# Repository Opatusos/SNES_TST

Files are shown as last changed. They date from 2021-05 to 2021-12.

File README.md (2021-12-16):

# SNES-TST

This projects intends to clean up the blurry RGB video on the 3-chip SNES by using the PPU2's test pins. The board has only been tried on a SNSP-CPU-01 motherboard but it should work with all revisions. The firmware is missing most of the board's functions. The planned functions are the following:
- dual analog ouput (verified, need further noise analysis, furthermore direct comparision is needed to the original video)
- Mode-7 patch for the test pins (verified)
- SuperCIC (verified)
- dual-frequency oscillator (not tested)
- controller support (partwise verified)
- dejitter (not tested)
- D4 patch (not tested)
- RGB LED support with PWM (not tested)

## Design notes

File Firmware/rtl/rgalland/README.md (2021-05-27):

# snes_cic_fpga
snes cic implementation with FPGA FireAnt board

https://www.crowdsupply.com/xips-technology/fireant

Personally I got this board from Mouser, but the board comes without the packaging that contains the serial number that is normally required to register the device with Efinix (https://www.efinixinc.com/products-efinity.html). I contacted them to create an account in order to download the IDE and have access to support.

FireAntInAction

FireAnt on the right connected to SMW PCB. Little LED next to USB conenctor is on showing that reset has been released. On the left of the image, there is PIC16F that I used to compare the outputs.

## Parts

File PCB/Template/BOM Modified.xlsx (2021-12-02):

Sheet: BOM Report
Bill of Materials
Source Data From: |  | Field=DataSourceFileName
Project: |  | Field=ProjectFileName
Variant: |  | Field=VariantName
Revision: |  | Field=Revision
Currency: |  | Field=Currency
Creation Date: | Field=ReportDate | Field=ReportTime
Print Date: | 2021-12-01 | 16:24:10
Column=Line # | Column=Quantity | Column=Designator | Column=Comment | Column=Footprint | Column=Manufacturer | Column=Manufacturer_Part_Number | Column=Supplier 1 | Column=Supplier Part Number 1 | Column=Supplier Unit Price 1 | Total Price
 |  |  |  |  |  |  |  |  |  | 0.00
 |  |  |  |  |  |  |  |  |  | 0.00
 |  |  |  |  |  |  |  |  |  | 0.00
 | 0 |  |  |  |  |  |  |  |  | $0.00

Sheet: Project Information
Project Filename | Field=ProjectFileName
Variant Name | Field=VariantName
Data-Source Filename | Field=DataSourceFileName
Title | Field=Title
Total Quantity | Field=TotalQuantity
Report Time | Field=ReportTime
Report Date | Field=ReportDate
Report Date & Tine | Field=ReportDateTime
Output Name | Field=OutputName
Output Type | Field=OutputType
Output Generator Name | Field=GeneratorName
Output Generator Description | Field=GeneratorDescription

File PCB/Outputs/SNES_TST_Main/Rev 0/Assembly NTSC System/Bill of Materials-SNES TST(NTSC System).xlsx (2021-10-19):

Pos # | Quantity | Designator | Value | Tolerance | Nominal Voltage | Dielectric | Footprint | Vendor | Part Number
1 | 27 | C1, C2, C3, C4, C5, C6, C11, C12, C13, C14, C15, C16, C17, C18, C19, C20, C21, C22, C23, C24, C25, C26, C27, C28, C29, C30, C32 | 100nF | +-20% | 10V | X7R | Cap_0402_Chip
2 | 4 | C7, C8, C9, C10 | 10pF | +-20% | 10V | X7R | Cap_0402_Chip
3 | 3 | C31, C33, C34 | 10nF | +-20% | 10V | X7R | Cap_0402_Chip
4 | 1 | C35 | 1uF | +-20% | 10V | X7R | Cap_0603_Chip
5 | 1 | C36 | 10uF | +-20% | 10V | X7R | Cap_0805_Chip
6 | 1 | C37 | 10uF | +-20% | 25V | X7R | Cap_1206_Chip
7 | 4 | D1, D2, D3, D4 | Schottky Diode |  |  |  | SOD323 | Diodes | BAT54WS-7-F
8 | 4 | FB1, FB2, FB3, FB4 | 1800Ohm 200mA |  |  |  | Ind_0402_Chip | TDK | MMZ1005S182ET000
9 | 1 | IC1 | 10M04SAE144C8G |  |  |  | EQFP-144_A:1P65_ | Intel | 10M08SAE144C8G
10 | 1 | IC2 | 17.734475 MHz |  |  |  | Quarz 7.5mm | IQD Frequency | LFSPXO020648Bulk
11 | 1 | IC3 | TMUX1219 |  |  |  | SOT23-6 | Texas Instruments | TMUX1219DBVR
12 | 1 | IC5 | SN74HCT541 |  |  |  | TSSOP20 Narrow | Texas Instruments | SN74HCT541PW
13 | 7 | IC6, IC7, IC8, IC9, IC10, IC11, IC12 | LSF0108 |  |  |  | VQFN20 | Texas Instruments | LSF0108RKS
14 | 2 | IC13, IC15 | OPA2356 |  |  |  | MSOP8 | Analog Devices | OPA2356AIDGK
15 | 1 | IC14 | TMUX1574 |  |  |  | SOT-23THIN16 | Texas Instruments | TMUX1574DYYR
16 | 1 | IC16 | ADV7123 |  |  |  | ST_48_ADI | Analog Devices Inc | ADV7123KSTZ50
17 | 1 | IC17 | THS7374 |  |  |  | TSSOP14 | Texas Instruments | THS7374IPW
18 | 1 | IC18 | MCP1703T |  |  |  | SOT223-3 | Microchip | MCP1703T-3302E/DB
19 | 1 | J2 | 80Pole Connector |  |  |  | DF40C-80DP | Hirose Connector | DF40C-80DP-0.4V(51)
20 | 1 | Q1 | IRLML6402 |  |  |  | SOT23_FET | Diodes | IRLML6402
21 | 1 | Q2 | MMBT3904 |  |  |  | SOT23_Transistor | Diodes | MMBT3904
22 | 1 | Q3 | BSS138 |  |  |  | SOT23_FET | Infenion | BSS138
23 | 6 | R1, R4, R28, R50, R55, R63 | 1k | +-1% |  |  | Res_0402_Chip
24 | 12 | R2, R3, R5, R17, R18, R19, R41, R42, R43, R58, R66, R78 | 10k | +-1% |  |  | Res_0402_Chip
25 | 5 | R6, R7, R12, R14, R44 | 470R | +-1% |  |  | Res_0603_Chip
26 | 4 | R8, R11, R13, R21 | 300R | +-1% |  |  | Res_0603_Chip
27 | 4 | R9, R49, R54, R60 | 0R |  |  |  | Res_0402_Chip
28 | 2 | R15, R20 | 33R | +-1% |  |  | Res_0603_Chip
29 | 1 | R16 | 100R | +-1% |  |  | Res_0603_Chip
30 | 8 | R22, R24, R25, R33, R34, R38, R39, R40 | 1.8k | +-1% |  |  | Res_0402_Chip
31 | 3 | R23, R26, R27 | 10k | +-1% |  |  | 1206_Array_Chip
32 | 7 | R29, R30, R31, R32, R35, R36, R37 | 200k | +-1% |  |  | Res_0402_Chip
33 | 1 | R45 | 1.24k | +-1% |  |  | Res_0402_Chip
34 | 4 | R46, R52, R57, R65 | 619R | +-1% |  |  | Res_0402_Chip
35 | 1 | R47 | 91R | +-1% |  |  | Res_0603_Chip
36 | 4 | R48, R53, R59, R81 | 100k | +-1% |  |  | Res_0402_Chip
37 | 3 | R51, R56, R64 | 237R | +-1% |  |  | Res_0402_Chip
38 | 1 | R61 | 470R | +-1% |  |  | Res_0402_Chip
39 | 1 | R62 | 11R | +-1% |  |  | Res_0402_Chip
40 | 6 | R67, R68, R69, R70, R77, R79 | 75R | +-1% |  |  | Res_0603_Chip
41 | 6 | R71, R72, R73, R74, R75, R76 | 75R | +-1% |  |  | Res_0402_Chip
42 | 3 | R80, R82, R83 | 3.3k | +-1% |  |  | Res_0402_Chip

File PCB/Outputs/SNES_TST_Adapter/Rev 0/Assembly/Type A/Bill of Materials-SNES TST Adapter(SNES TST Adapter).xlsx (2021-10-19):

Pos # | Quantity | Designator | Value | Tolerance | Nominal Voltage | Dielectric | Footprint | Vendor | Part Number
1 | 1 | J1 | 80Pole Connector |  |  |  | DF40C-80DS | Hirose Connector | DF40C-80DS-0.4V(51)

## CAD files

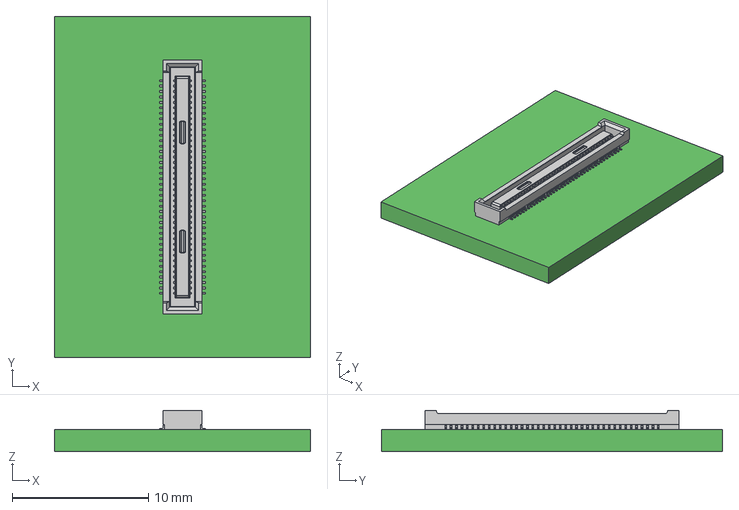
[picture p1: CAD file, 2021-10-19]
PCB/Outputs/SNES_TST_Adapter/Rev 0/Documentation/Type A/SNES TST Adapter Type A(SNES TST Adapter).step
18.8 x 25.0 x 3.04 mm
DF40C-80DS

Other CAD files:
PCB/Outputs/SNES_TST_Adapter/Rev 0/Documentation/Type B/SNES TST Adapter Type B(SNES TST Adapter).step

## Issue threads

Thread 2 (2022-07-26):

WE-MAPI_3020 Inductor

unmaker64, 2022-07-26:
Hi is this the correct inductor?

https://www.mouser.com/ProductDetail/Wurth-Elektronik/74438336068?qs=iC14BvcgY%2F2jjdn7Q0ci3w%3D%3D

Also wondering if this project will still be worked on, if you don't mind sharing.

Thanks

Opatusos, 2022-07-26:
Hi!

Is it from the dev branch? This inductor should be the correct one.
It is being worked on in theory, but I have not touched it since January. Hopefully I will find some time for it soon.

unmaker64, 2022-07-26:
Thank you for the quick reply!

I'm not sure how to find the most recent BOM within the dev branch tbh.

I had a look at the PCB in Altium and could see the part is described as "WE-MAPI_3020". These WE-MAPI_3020 inductors range in value from 330 nH to 10 uH. I tried to determine the correct value by looking at the datasheet for the ADP2370 and found this:

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

Using that formula I get an inductance value of 6.8 uH, assuming the Vout is 3.3v and the switching frequency is 1.2 MHz. I'm sort of guessing here so I wanted to check with you.

unmaker64, 2022-07-26:
I'm glad to hear that you haven't abandoned it! I look forward to seeing your progress on this when you have the time.

I'm not in a hurry to assemble a board anyway as I can't find the 10m04sae144c8g in stock anywhere. Which brings up another question I have: are other Altera MAX 10 FPGA's compatible? For example, a 10m08sae144c8g or 10M50SAE144I7G? A few of those have sold recently on ebay, which is the only place I've been able to find an FPGA.

Opatusos, 2022-07-27:
You were correct, it is 6.8 uH, but for some reason it shows 0603 in the comment field instead of the value. I really like this ADP2370 combined with the LT3045 LDO. I have also made an LM7805 replacement board with these two. It delivers up to 800 mA and has reasonably low noise.

The FPGA should be compatible up to 10M25SA, but not with the 10M50SA. Not sure what is the difference.
I have attached a quick export of the BOM. But as I see most of the semiconductors are not in stock unfortunately.
[SNES TST Main.xlsx](https://github.com/Opatusos/SNES_TST/files/9203990/SNES.TST.Main.xlsx)

unmaker64, 2022-07-28:
I really appreciate the BOM export. I was making my own by looking at the PCB in Altium.

In the BOM I can see the ferrite beads you've chosen are 0402 in size yet the PCB footprint is 0603. I know, not a big deal as 0402 components can fit in a 0603 footprint. I'm just wondering if that was a small mistake. I had picked these just to match the 0603 footprint:

https://www.mouser.com/ProductDetail/810-MMZ1608R102ATD25

Yeah the parts shortage really sucks. I figured I'd order what's currently available before they go out of stock again. I've been able to find more than I expected actually. What I have left to find now are the:

1. FPGA
2. DAC
3. clock
4. TMUX1574DYYR
5. IRLML6402

A few of those are available on ebay/aliexpress. I might take a gamble on them if it comes to that. If/when I'm able to find the remaining parts then I'll order some PCBs and report back here. Thanks again for your time.

Opatusos, 2022-08-04:
Yeah, I've changed the ferrite but did not change the details yet, as it was/is still WIP.

I have never tested this new version in the dev branch, so I'm not sure if it works at all. I still wanted to change the RGB lines from single-ended to differential. Right now I get GND interference if I connect the RGB signals to the Multiout connector.

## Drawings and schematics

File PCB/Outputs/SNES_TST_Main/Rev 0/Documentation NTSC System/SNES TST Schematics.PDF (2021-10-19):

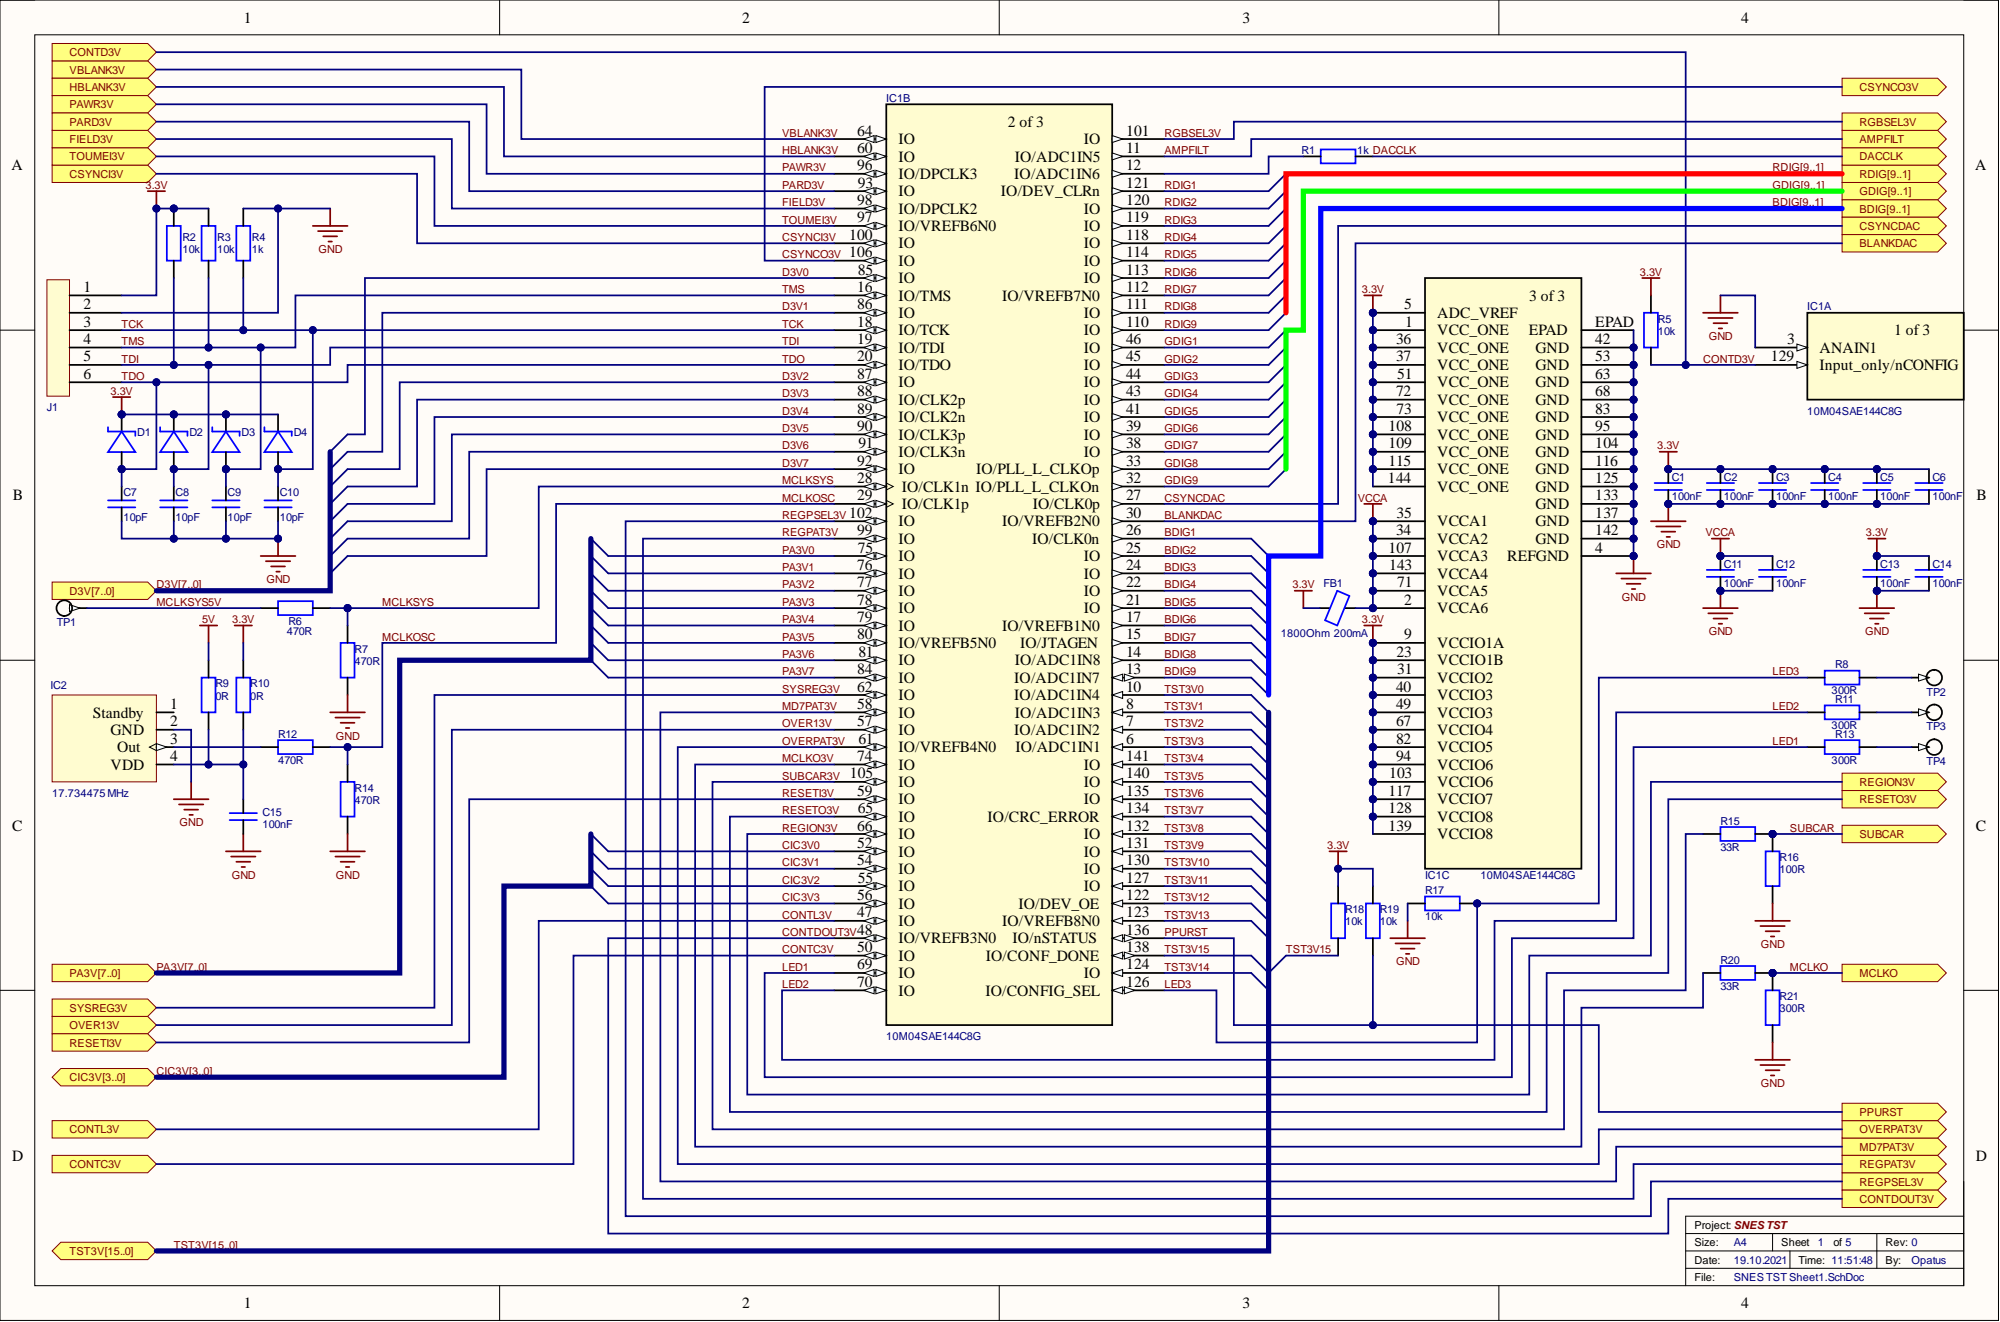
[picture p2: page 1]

H B L A N K 3 | V 6 0 | 1 1
P AW R 3 V | 9 6 | 1 2 | | | R D I G [ 9 . . 1 ]

T O UME I 3 | 9 7 V | 1 1 9 R D I G 3

123456 T C K | | | | T C K | 1 8 | 1 1 0 | R D I G 9 | 1 | A DC_ V RE F VCC_ O N E E PA D VCC_ O N E G N D VCC_ O N E G N D | E PA D | C O | N D | 3 | A N In p | 1 of 3 A IN 1 u t _ o n l y / n C O N FI G

R E G PAT 3 | 9 9 V | 3 V | 3 4 | VCCA 2 G N D VCCA 3 REFG N D VCCA 4 VCCA 5 VCCA 6 VCCIO 1 A VCCIO 1 B VCCIO 2 VCCIO 3 | 1 4 2 | C A G R

C I C 3 V 0 | 5 2
C I C 3 V 1 | 5 4

C I C 3 V 3 | 5 6
C O N T L 3 V | 4 7
C O N T D O | 4 8 U T 3 V
C O N T C 3 V | 5 0 | | 1 3 8 1 2 4 1 2 6 | T S T 3 V 1 5 T S T 3 V 1 4 L E D 3 | T S T 3 V 1 5

i z : A | f | R v
a . | ime | B y O p u s

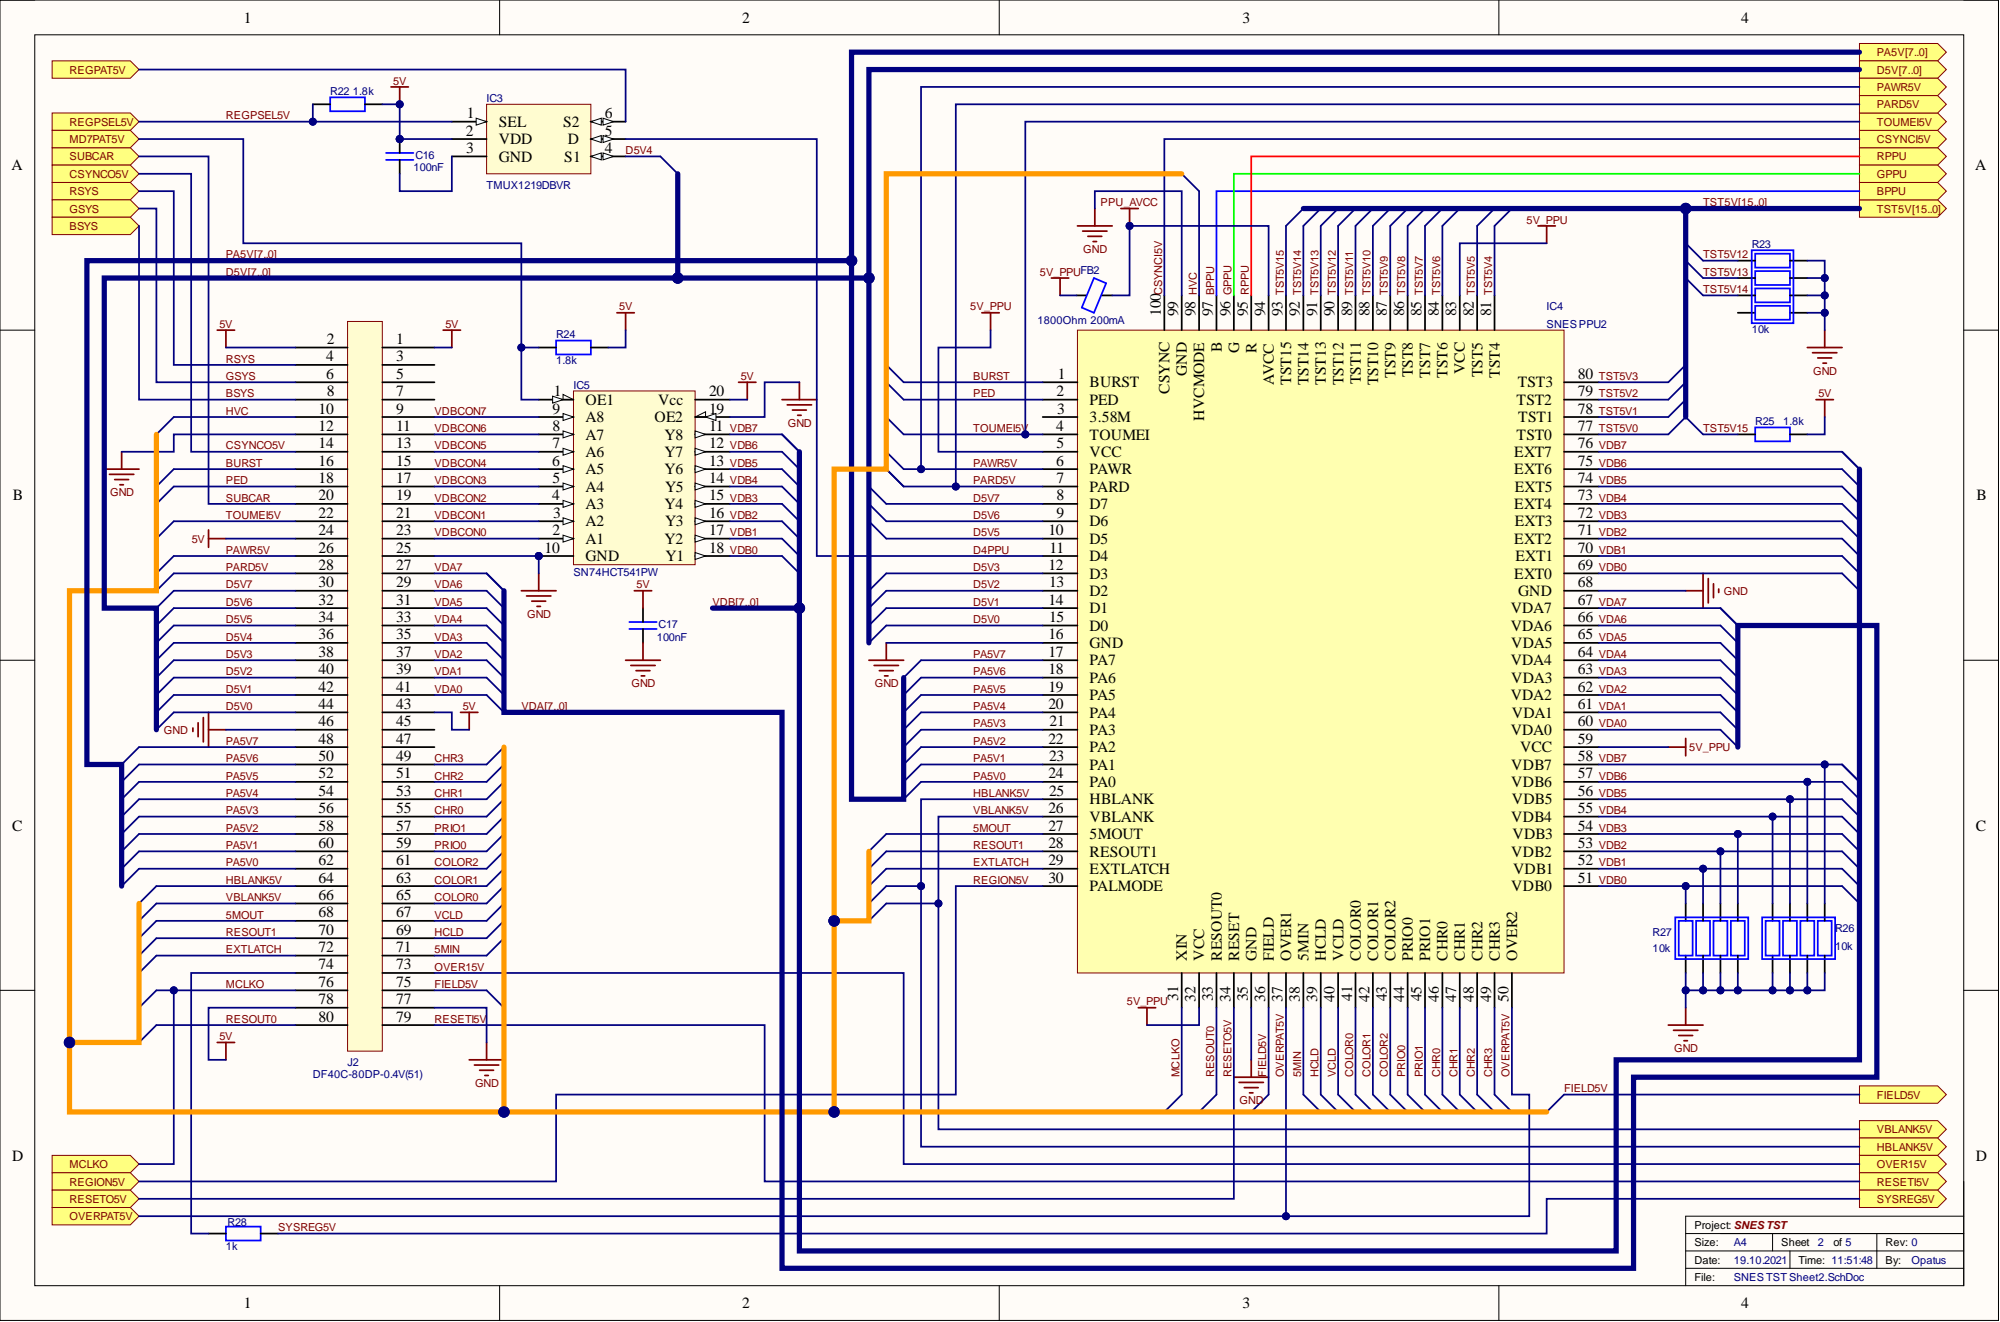
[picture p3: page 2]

P A
D 5 V [ 7 . . 0 ] | | | | | 5 V _ P P U F B | 2 | T S T 5 V 1 3
5 | 5 | V 5 V | 5 V _ P P U | 1 | hm | | T S T 5 V 1 4

5MIN 38 OVER1 37 FIELD 36 GND 35 RESET 34 RESOUT0 33 VCC 32 XIN 31

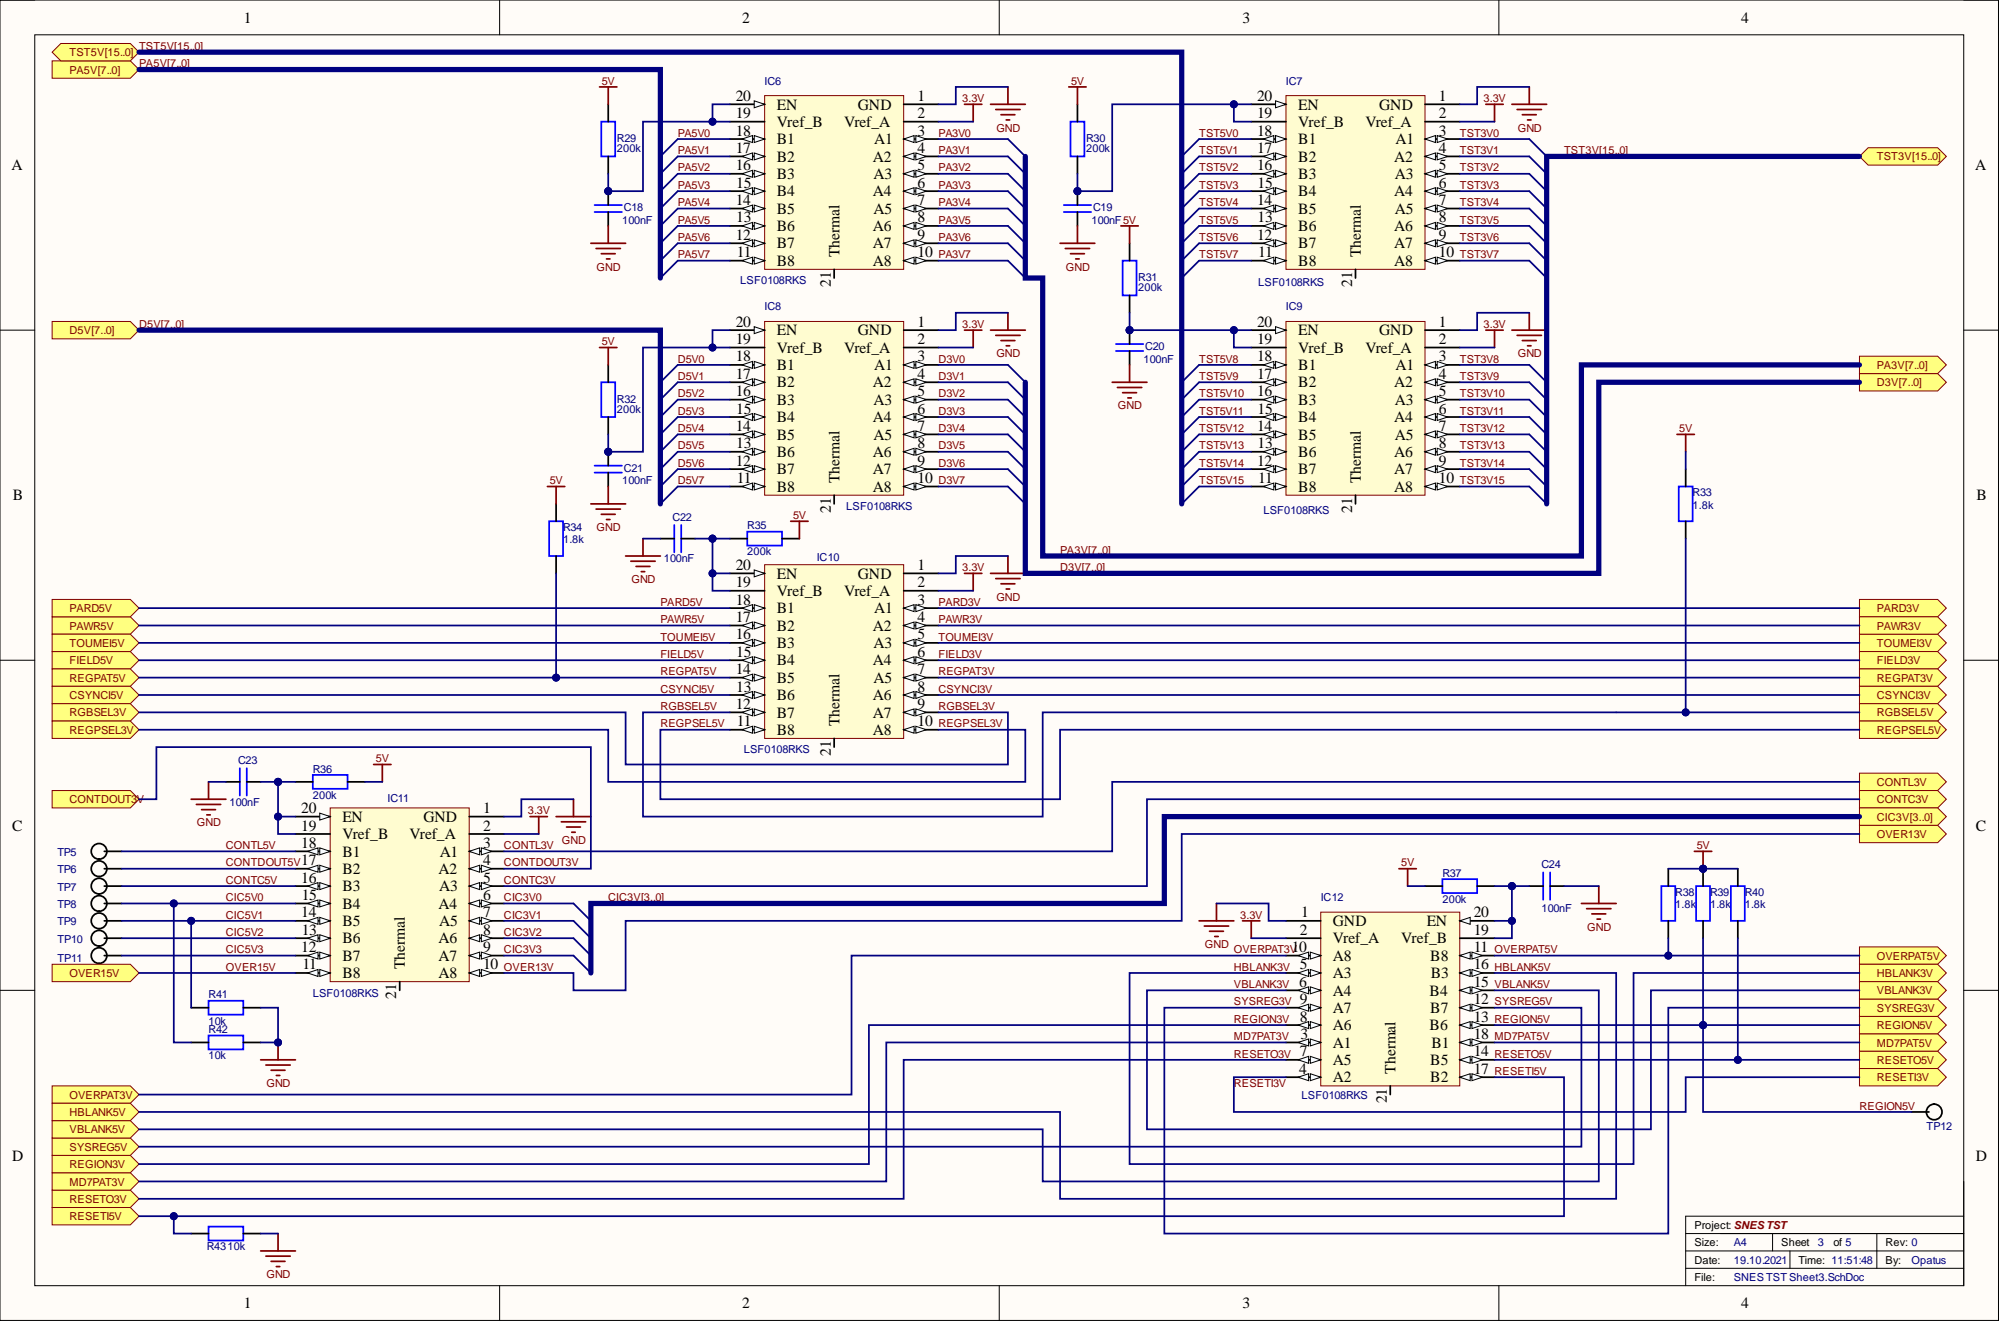
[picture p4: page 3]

4 | C O N T D O U T 3 V | | 5 V C 2 4
5 | C O N T C 3 V
6 C I C 3 V 0 | 3 V [ 3 . . 0 ] | I C 1 2

S Y S R E G 3 | 9 V | | 1 S Y S R E G 5 V
R E G I O N 3 | 8 V | A 6 A 1 B1 A 5 A 2 B2 | 13 8 B6 R E G I O N 5 V

R 4 2 | | | | MD 7 PAT 3 | V 3 | | 1 MD 7 PAT 5 V

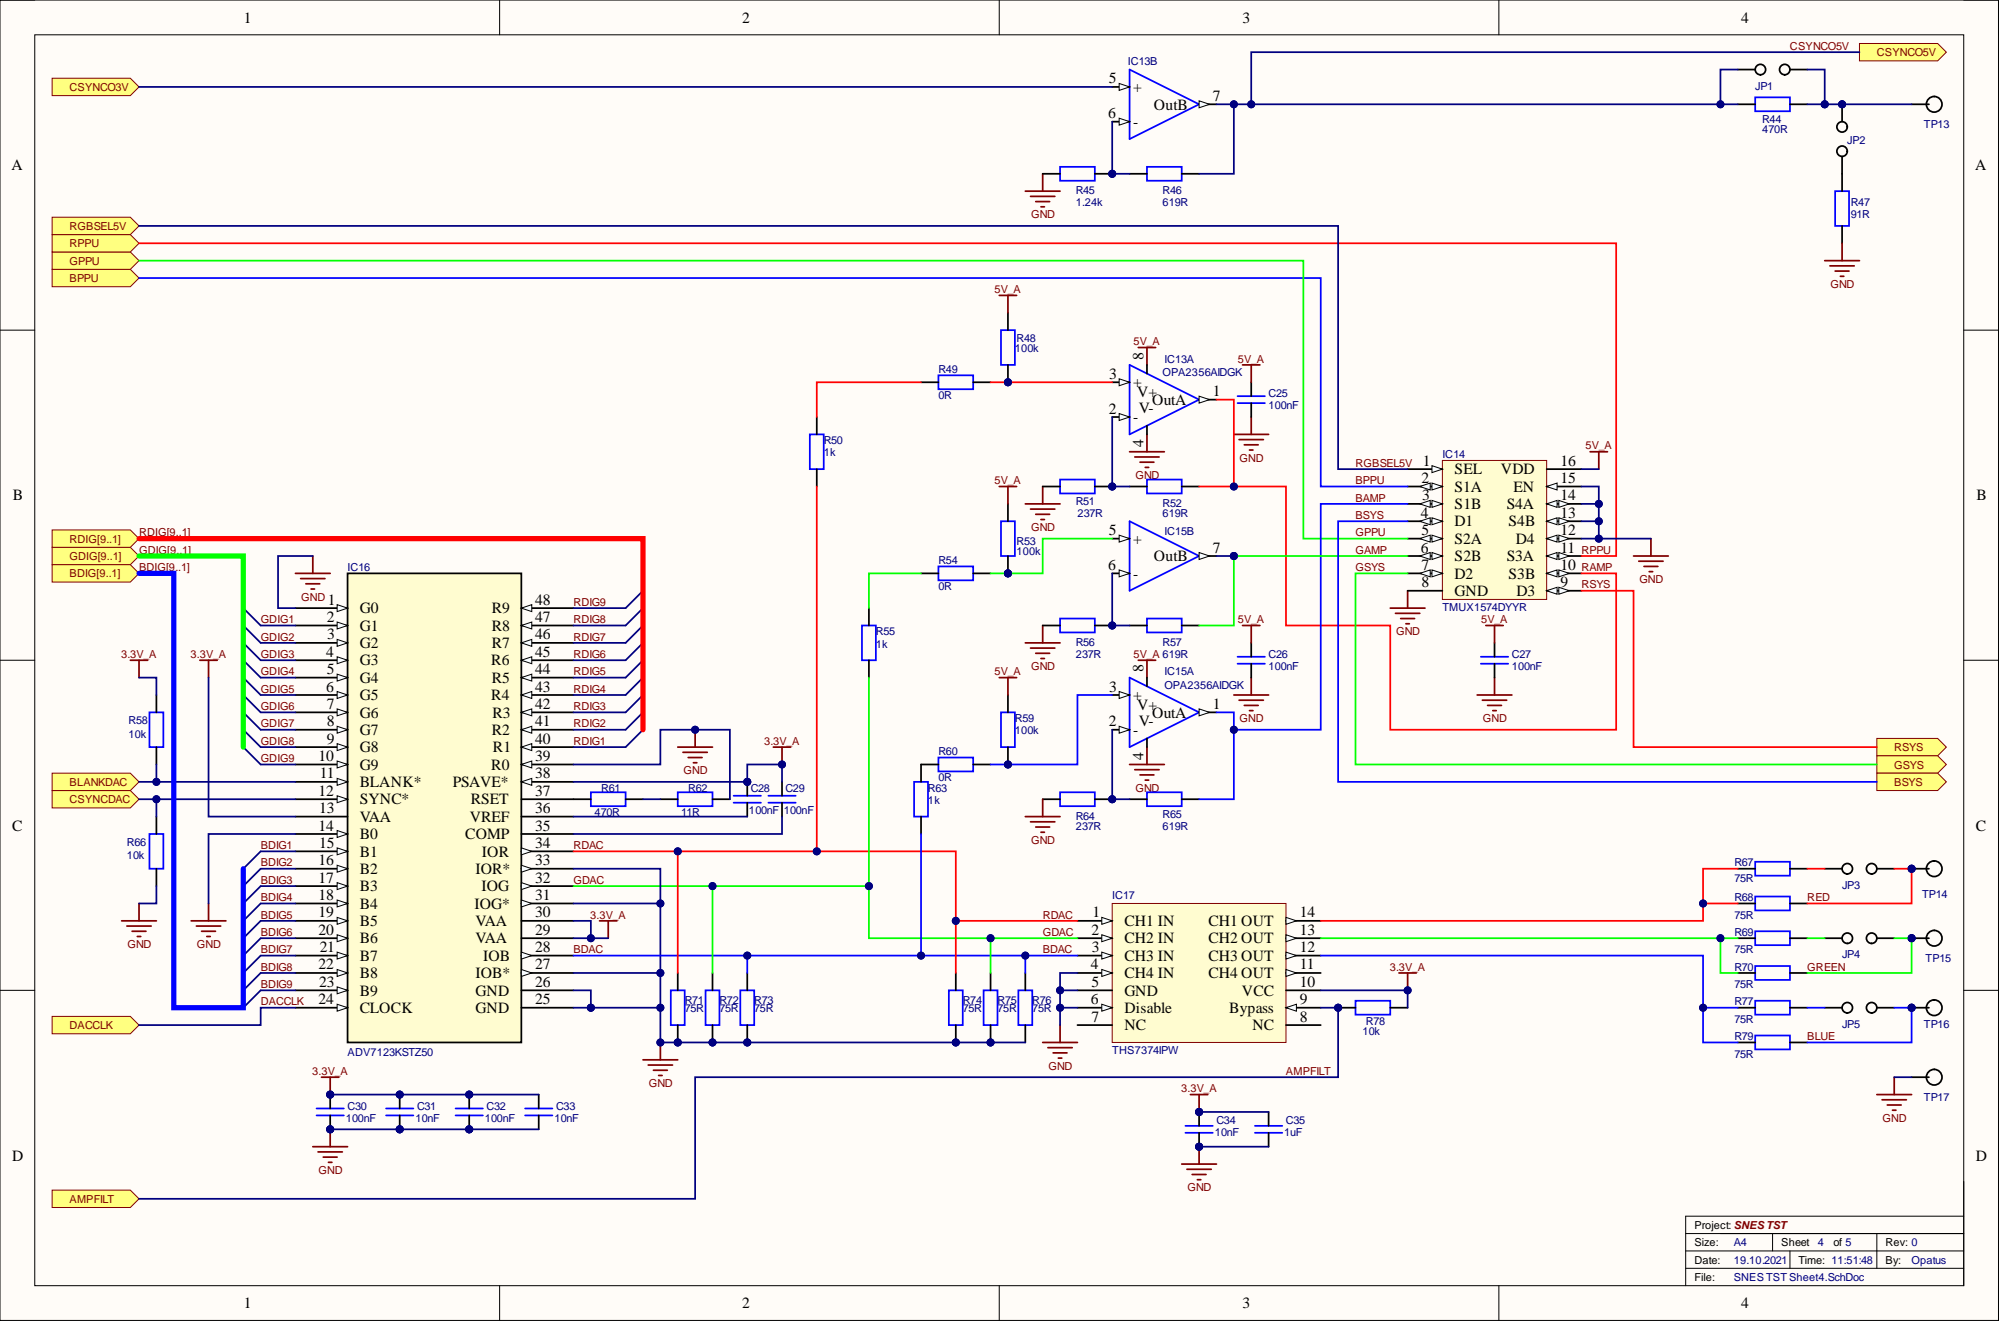
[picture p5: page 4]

GPPU | S2A 5

GDIG[9..1] | | | GAMP | S2B 6 | RPPU
BDIG[9..1] | | IC16 | | | | GSYS | D2 7 | RAMP

GND

SYNC* 12 | R61 R62
VAA 13

BDIG1 BDIG2 BDIG3 BDIG4 | B1 15 B2 16 B3 17 B4 18 | RDAC

Size: A4 | Sheet 4 of 5 | Rev: 0
Date: 19.10.2021 | Time: 11:51:48 | By: Opatus

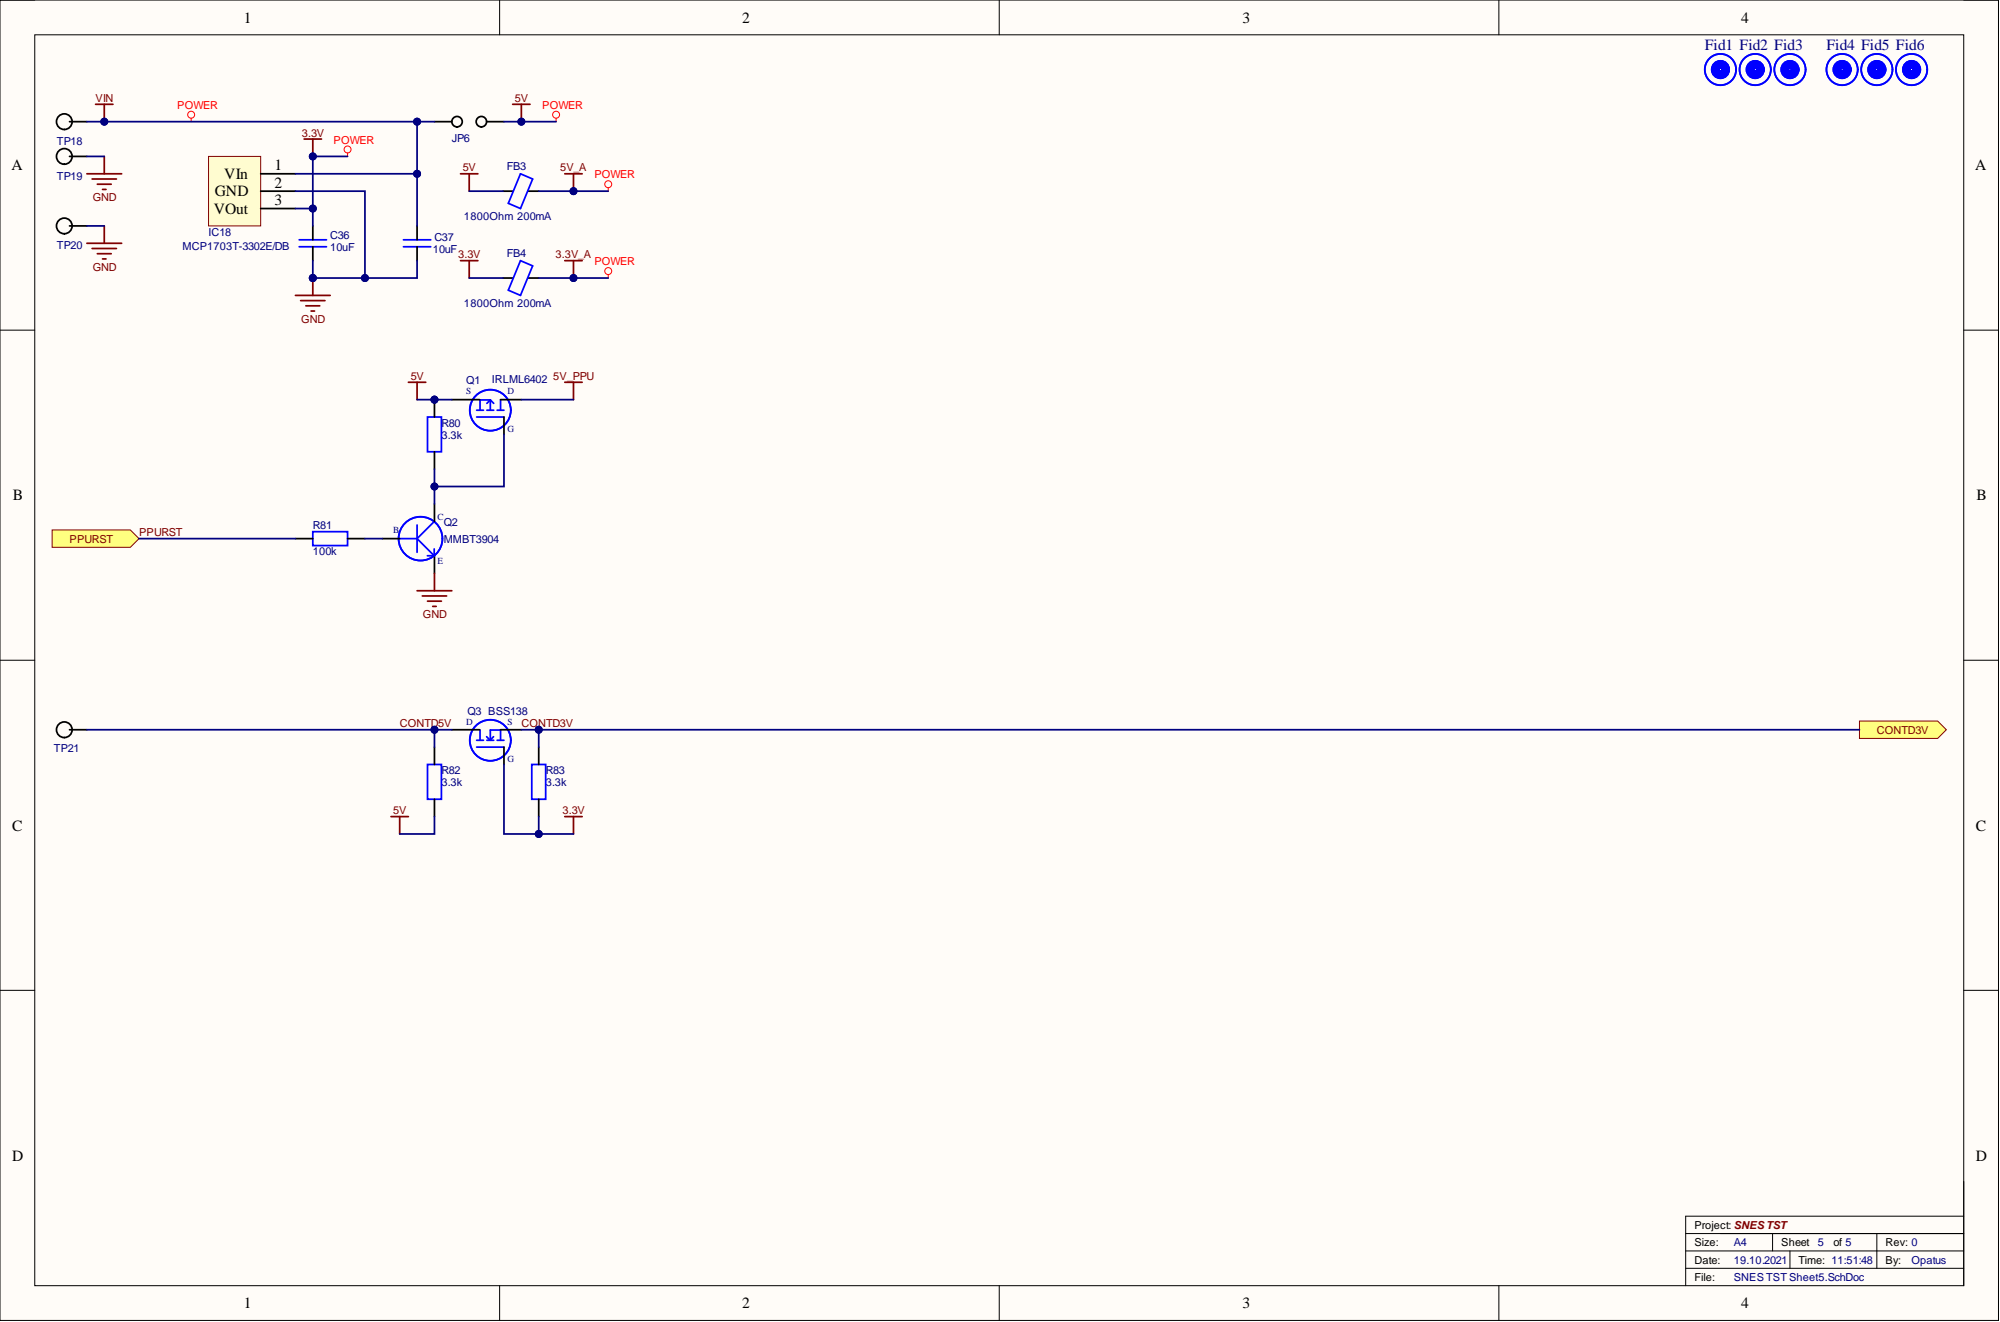
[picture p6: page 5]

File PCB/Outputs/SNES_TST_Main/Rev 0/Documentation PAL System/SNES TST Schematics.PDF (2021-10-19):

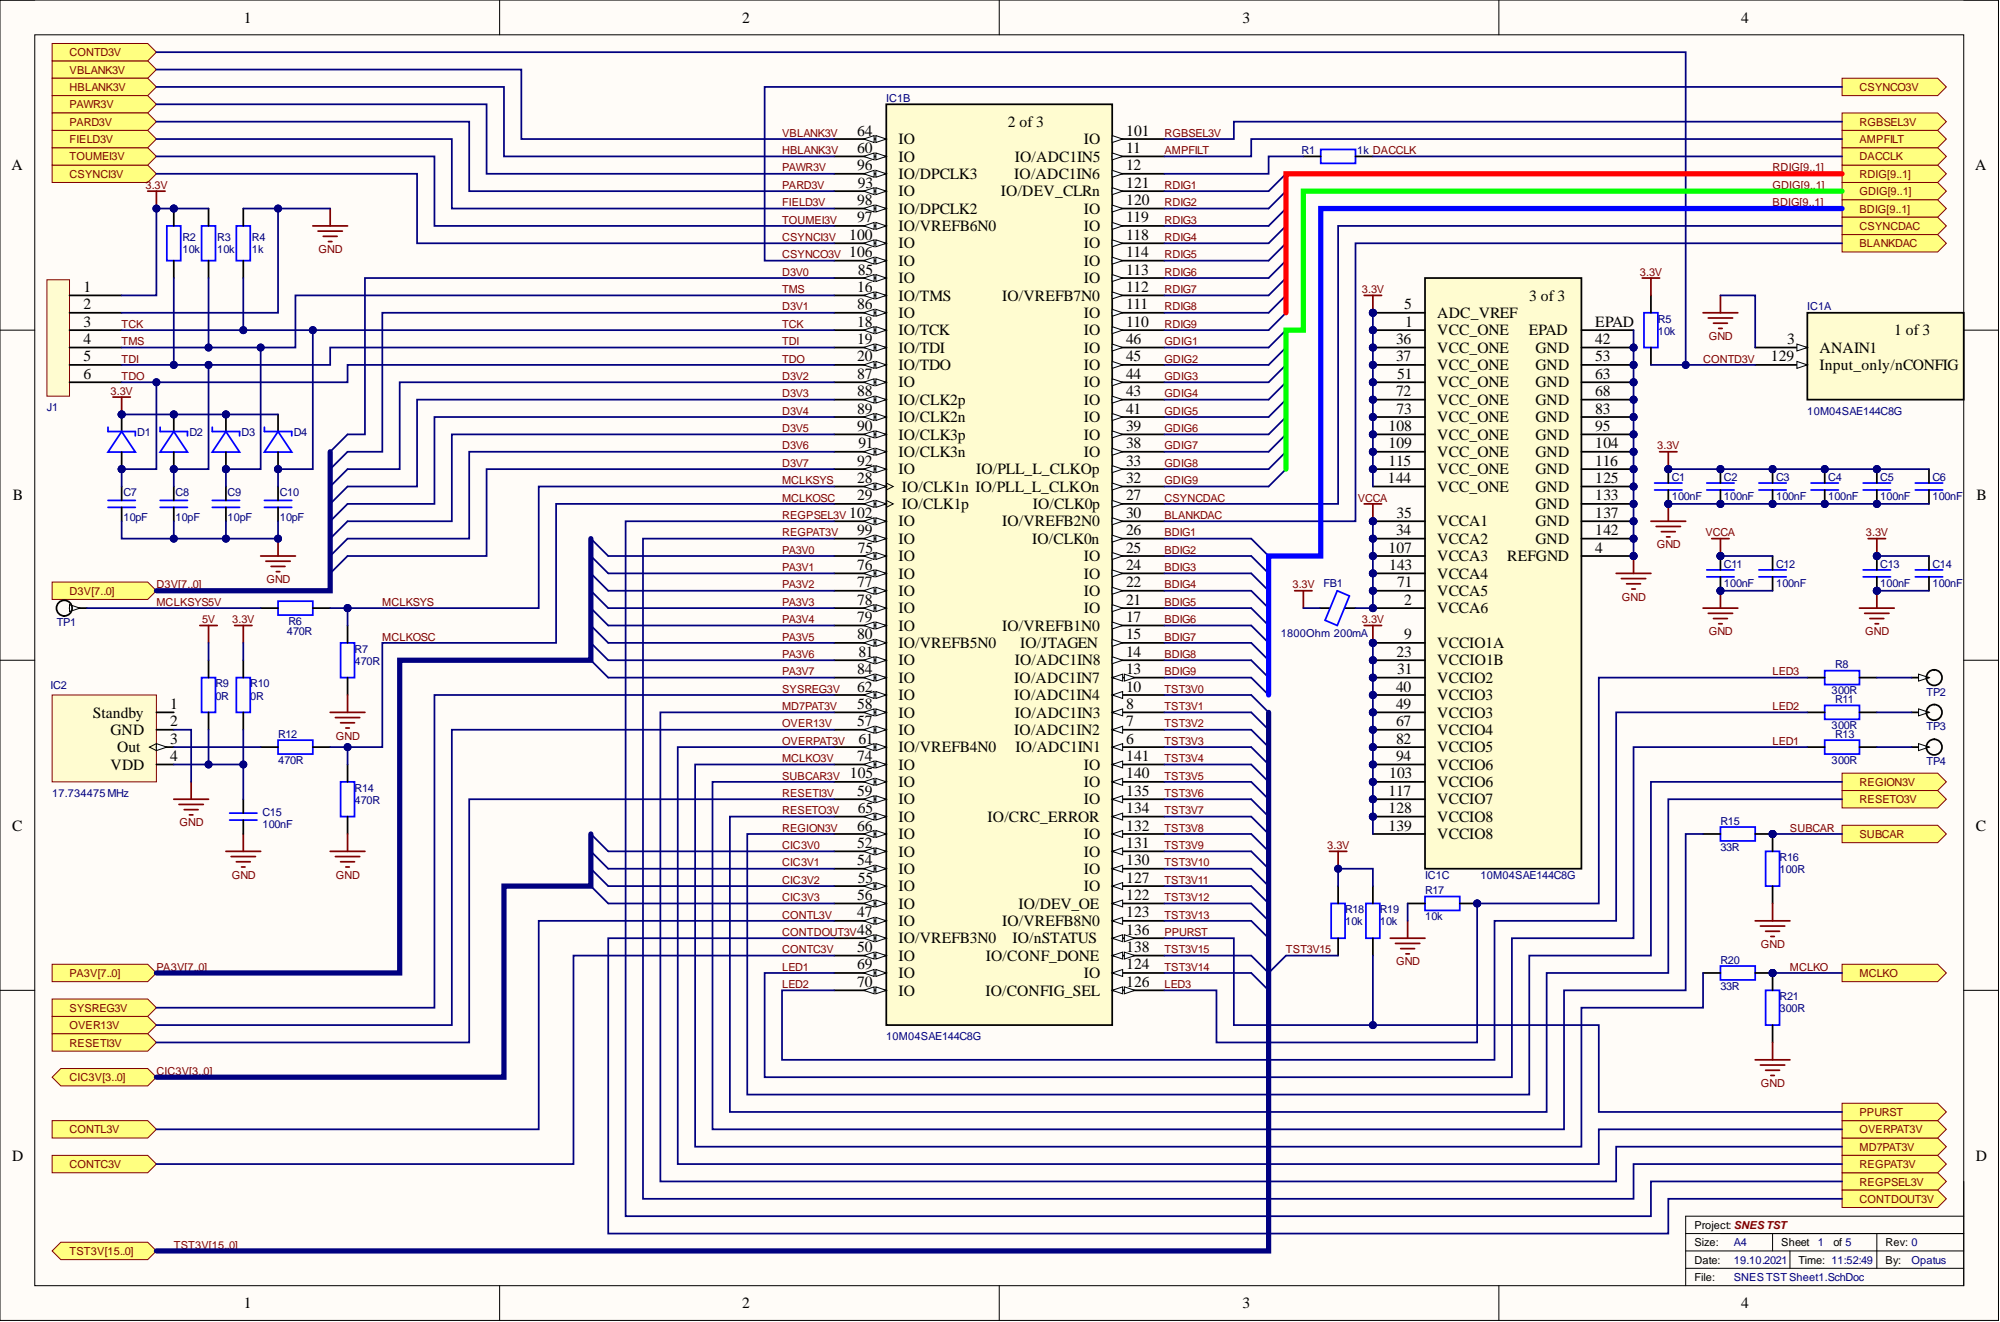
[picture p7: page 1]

H B L A N K 3 | V 6 0 | 1 1
P AW R 3 V | 9 6 | 1 2 | | | R D I G [ 9 . . 1 ]

T O UME I 3 | 9 7 V | 1 1 9 R D I G 3

123456 T C K | | | | T C K | 1 8 | 1 1 0 | R D I G 9 | 1 | A DC_ V RE F VCC_ O N E E PA D VCC_ O N E G N D VCC_ O N E G N D | E PA D | C O | N D | 3 | A N In p | 1 of 3 A IN 1 u t _ o n l y / n C O N FI G

R E G PAT 3 | 9 9 V | 3 V | 3 4 | VCCA 2 G N D VCCA 3 REFG N D VCCA 4 VCCA 5 VCCA 6 VCCIO 1 A VCCIO 1 B VCCIO 2 VCCIO 3 | 1 4 2 | C A G R

C I C 3 V 0 | 5 2
C I C 3 V 1 | 5 4

C I C 3 V 3 | 5 6
C O N T L 3 V | 4 7
C O N T D O | 4 8 U T 3 V
C O N T C 3 V | 5 0 | | 1 3 8 1 2 4 1 2 6 | T S T 3 V 1 5 T S T 3 V 1 4 L E D 3 | T S T 3 V 1 5

i z : A | f | R v
a . | ime | B y O p u s

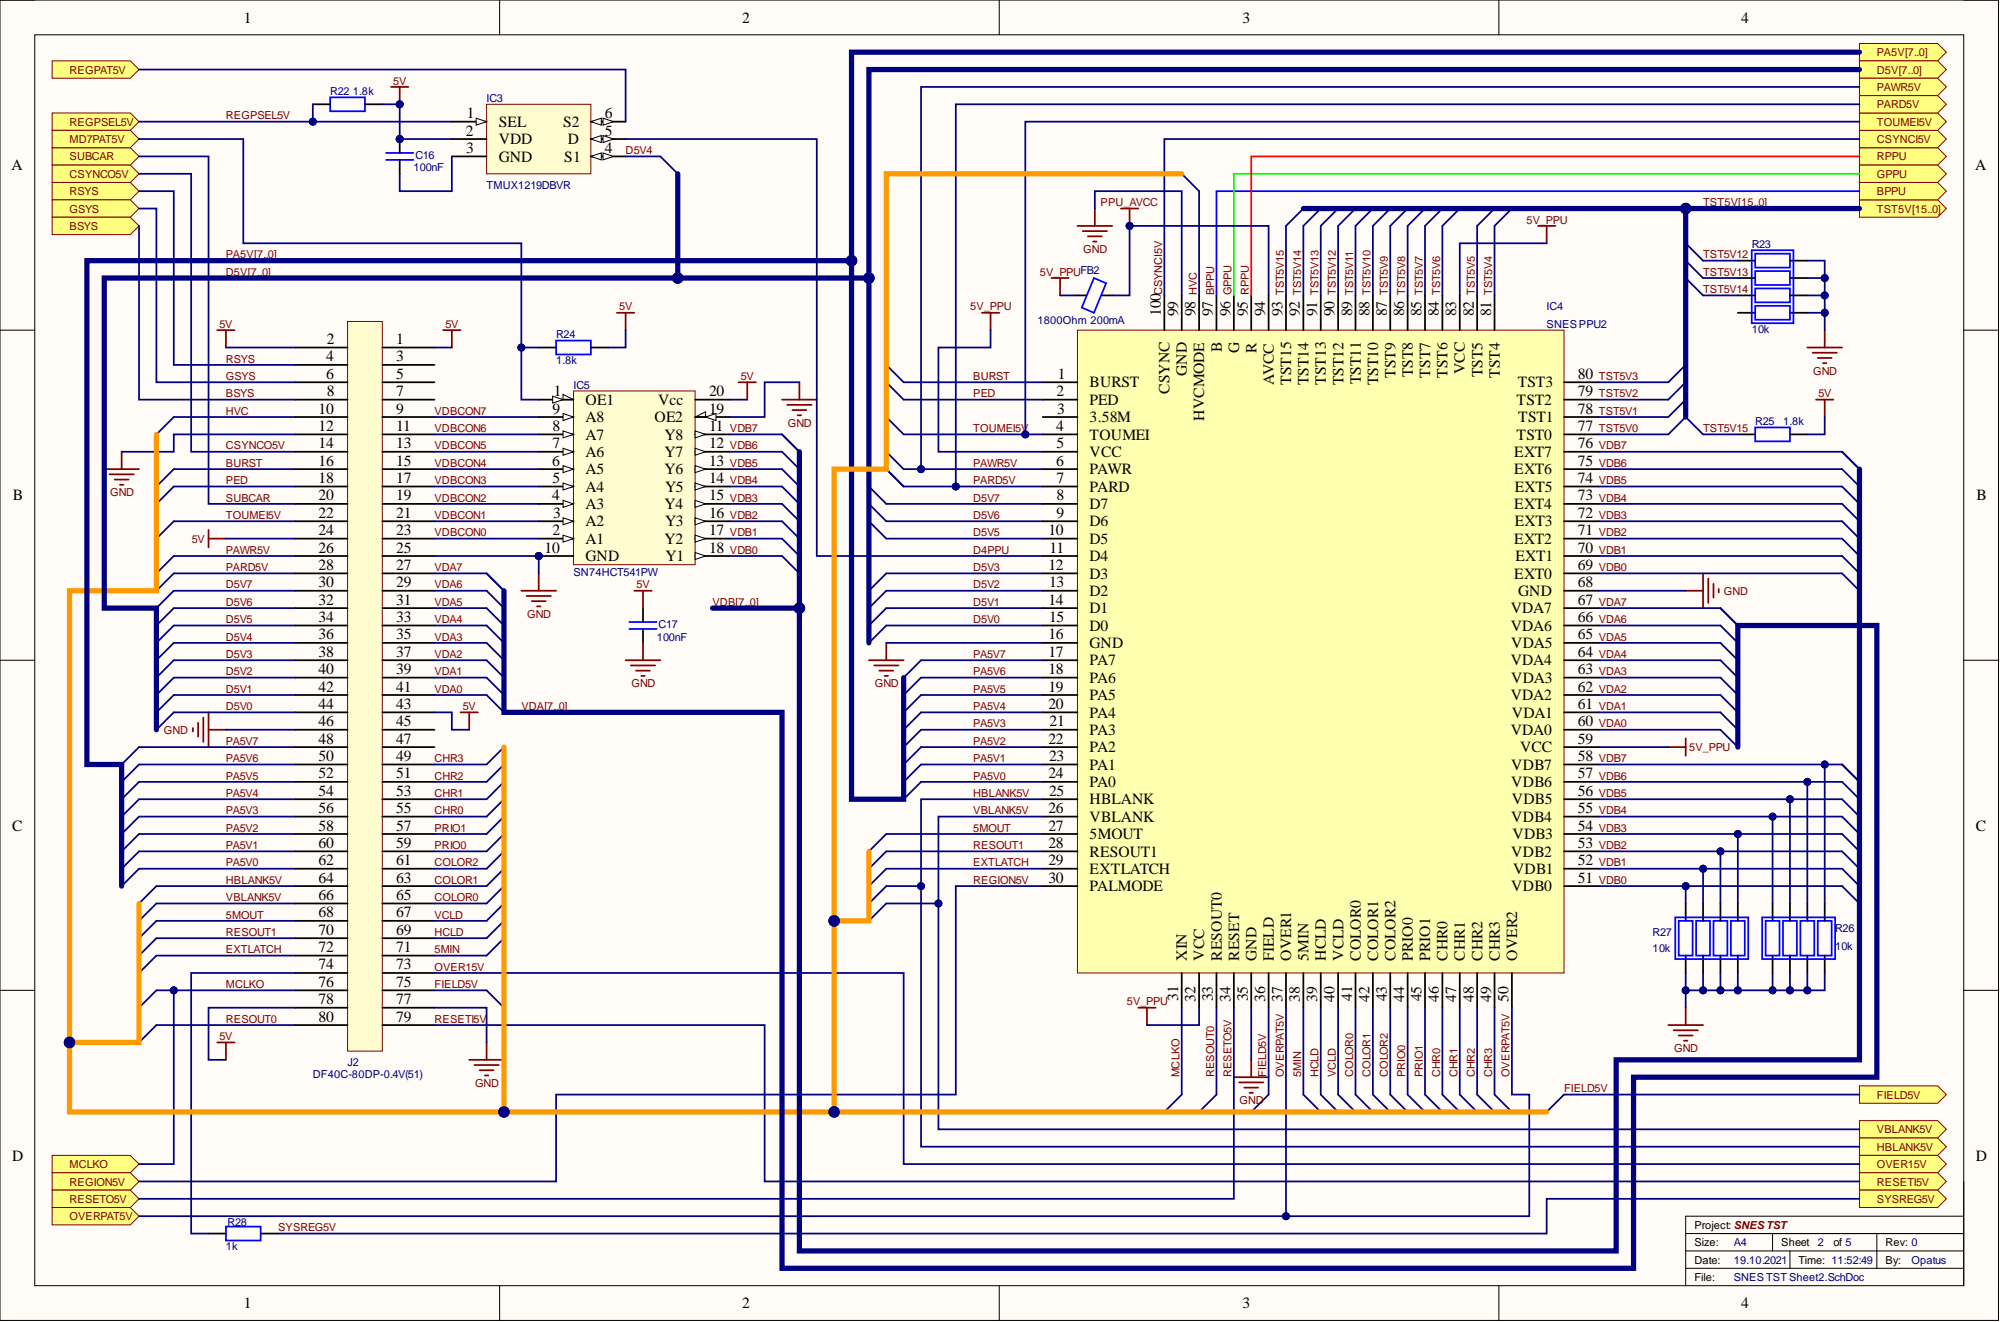
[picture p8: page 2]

P A
D 5 V [ 7 . . 0 ] | | | | | 5 V _ P P U F B | 2 | T S T 5 V 1 3
5 | 5 | V 5 V | 5 V _ P P U | 1 | hm | | T S T 5 V 1 4

5MIN 38 OVER1 37 FIELD 36 GND 35 RESET 34 RESOUT0 33 VCC 32 XIN 31

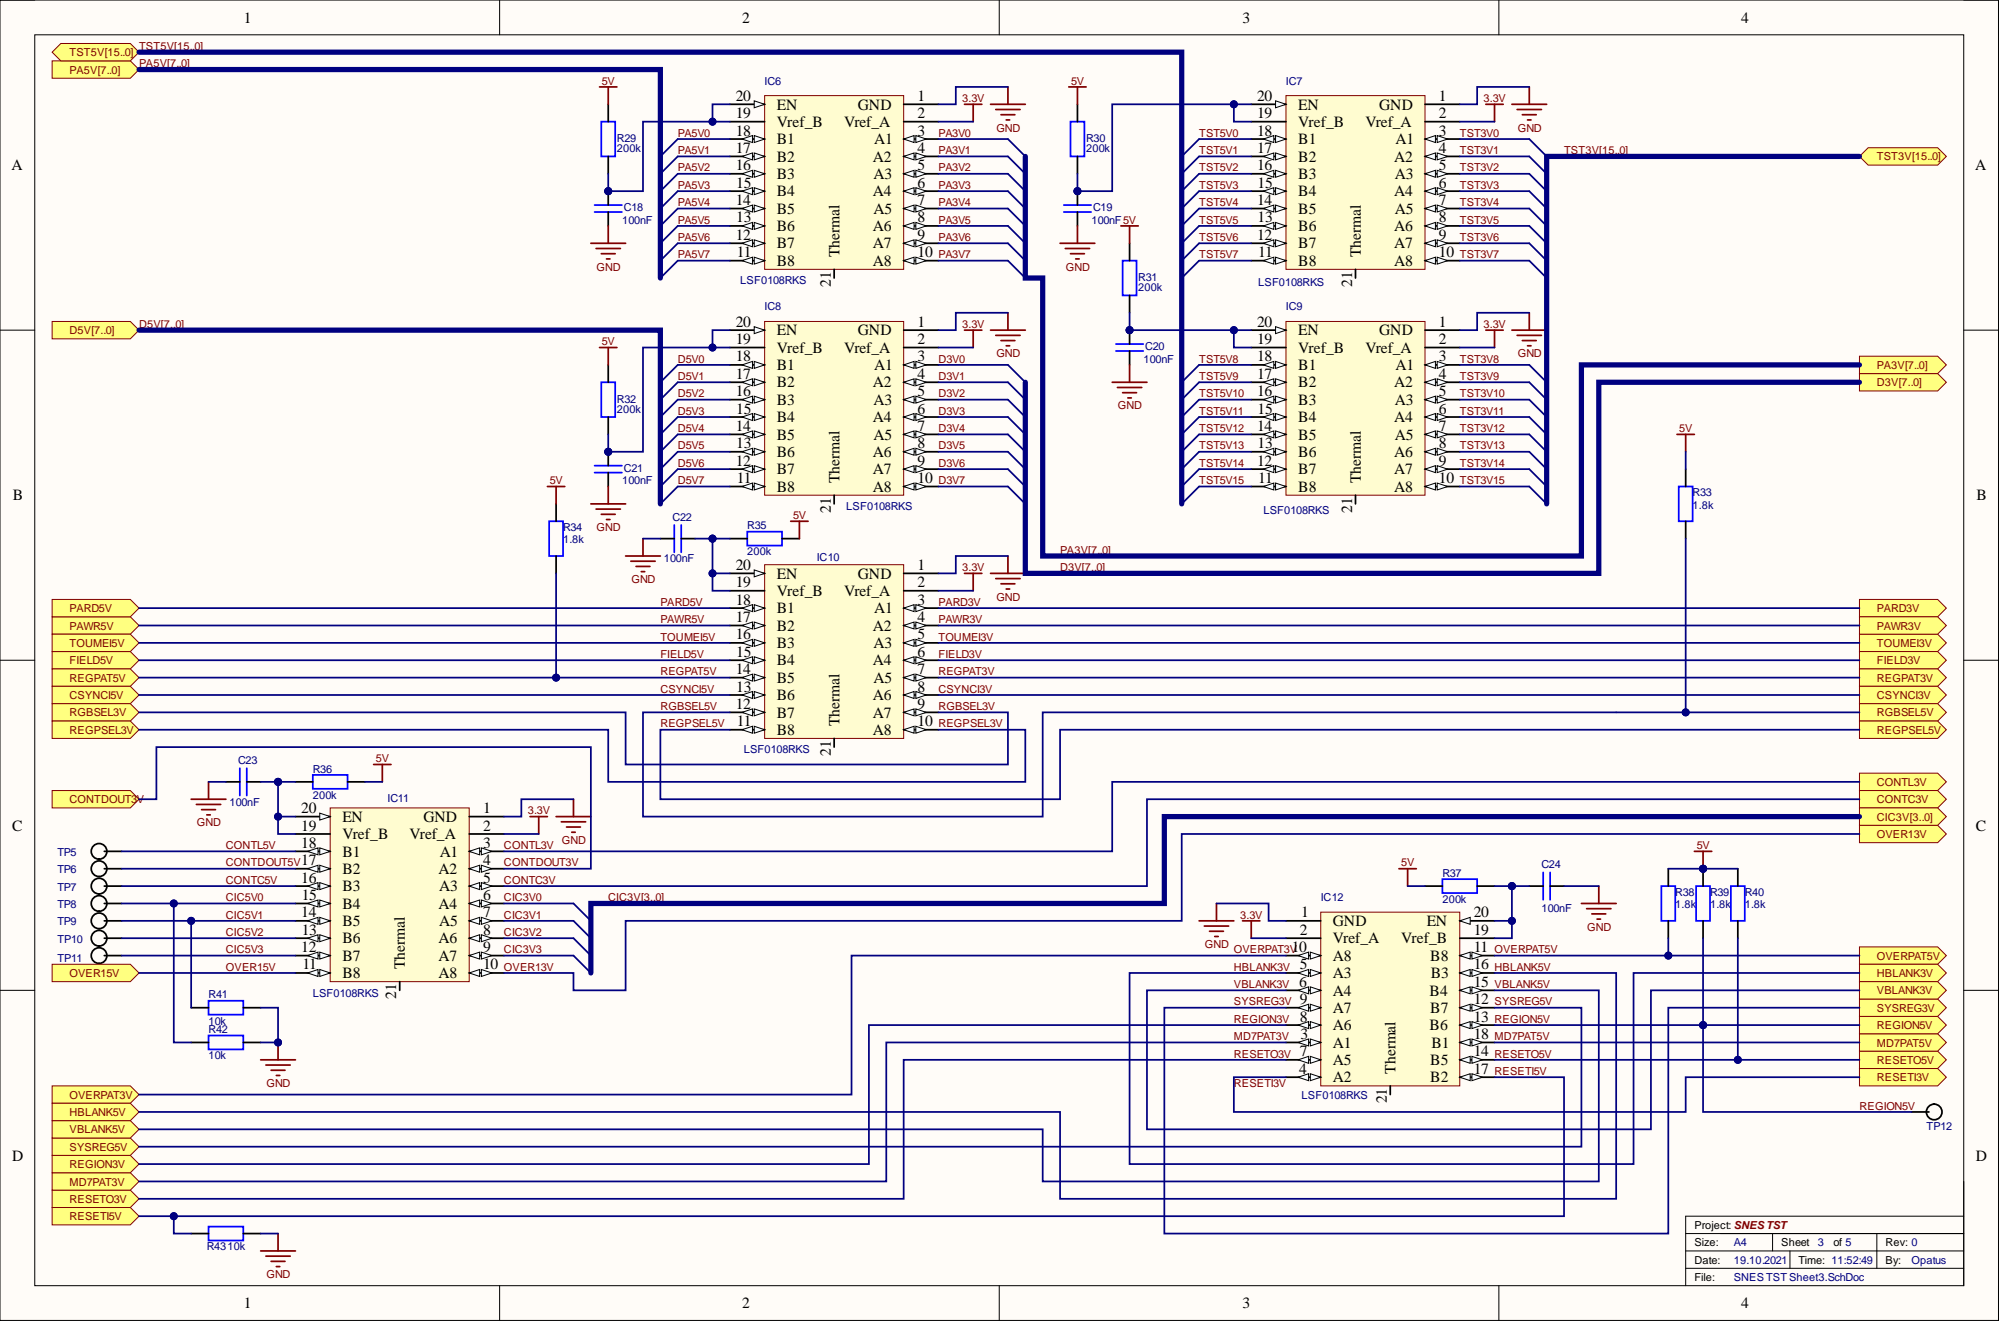
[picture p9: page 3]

4 | C O N T D O U T 3 V | | 5 V C 2 4
5 | C O N T C 3 V
6 C I C 3 V 0 | 3 V [ 3 . . 0 ] | I C 1 2

S Y S R E G 3 | 9 V | | 1 S Y S R E G 5 V
R E G I O N 3 | 8 V | A 6 A 1 B1 A 5 A 2 B2 | 13 8 B6 R E G I O N 5 V

R 4 2 | | | | MD 7 PAT 3 | V 3 | | 1 MD 7 PAT 5 V

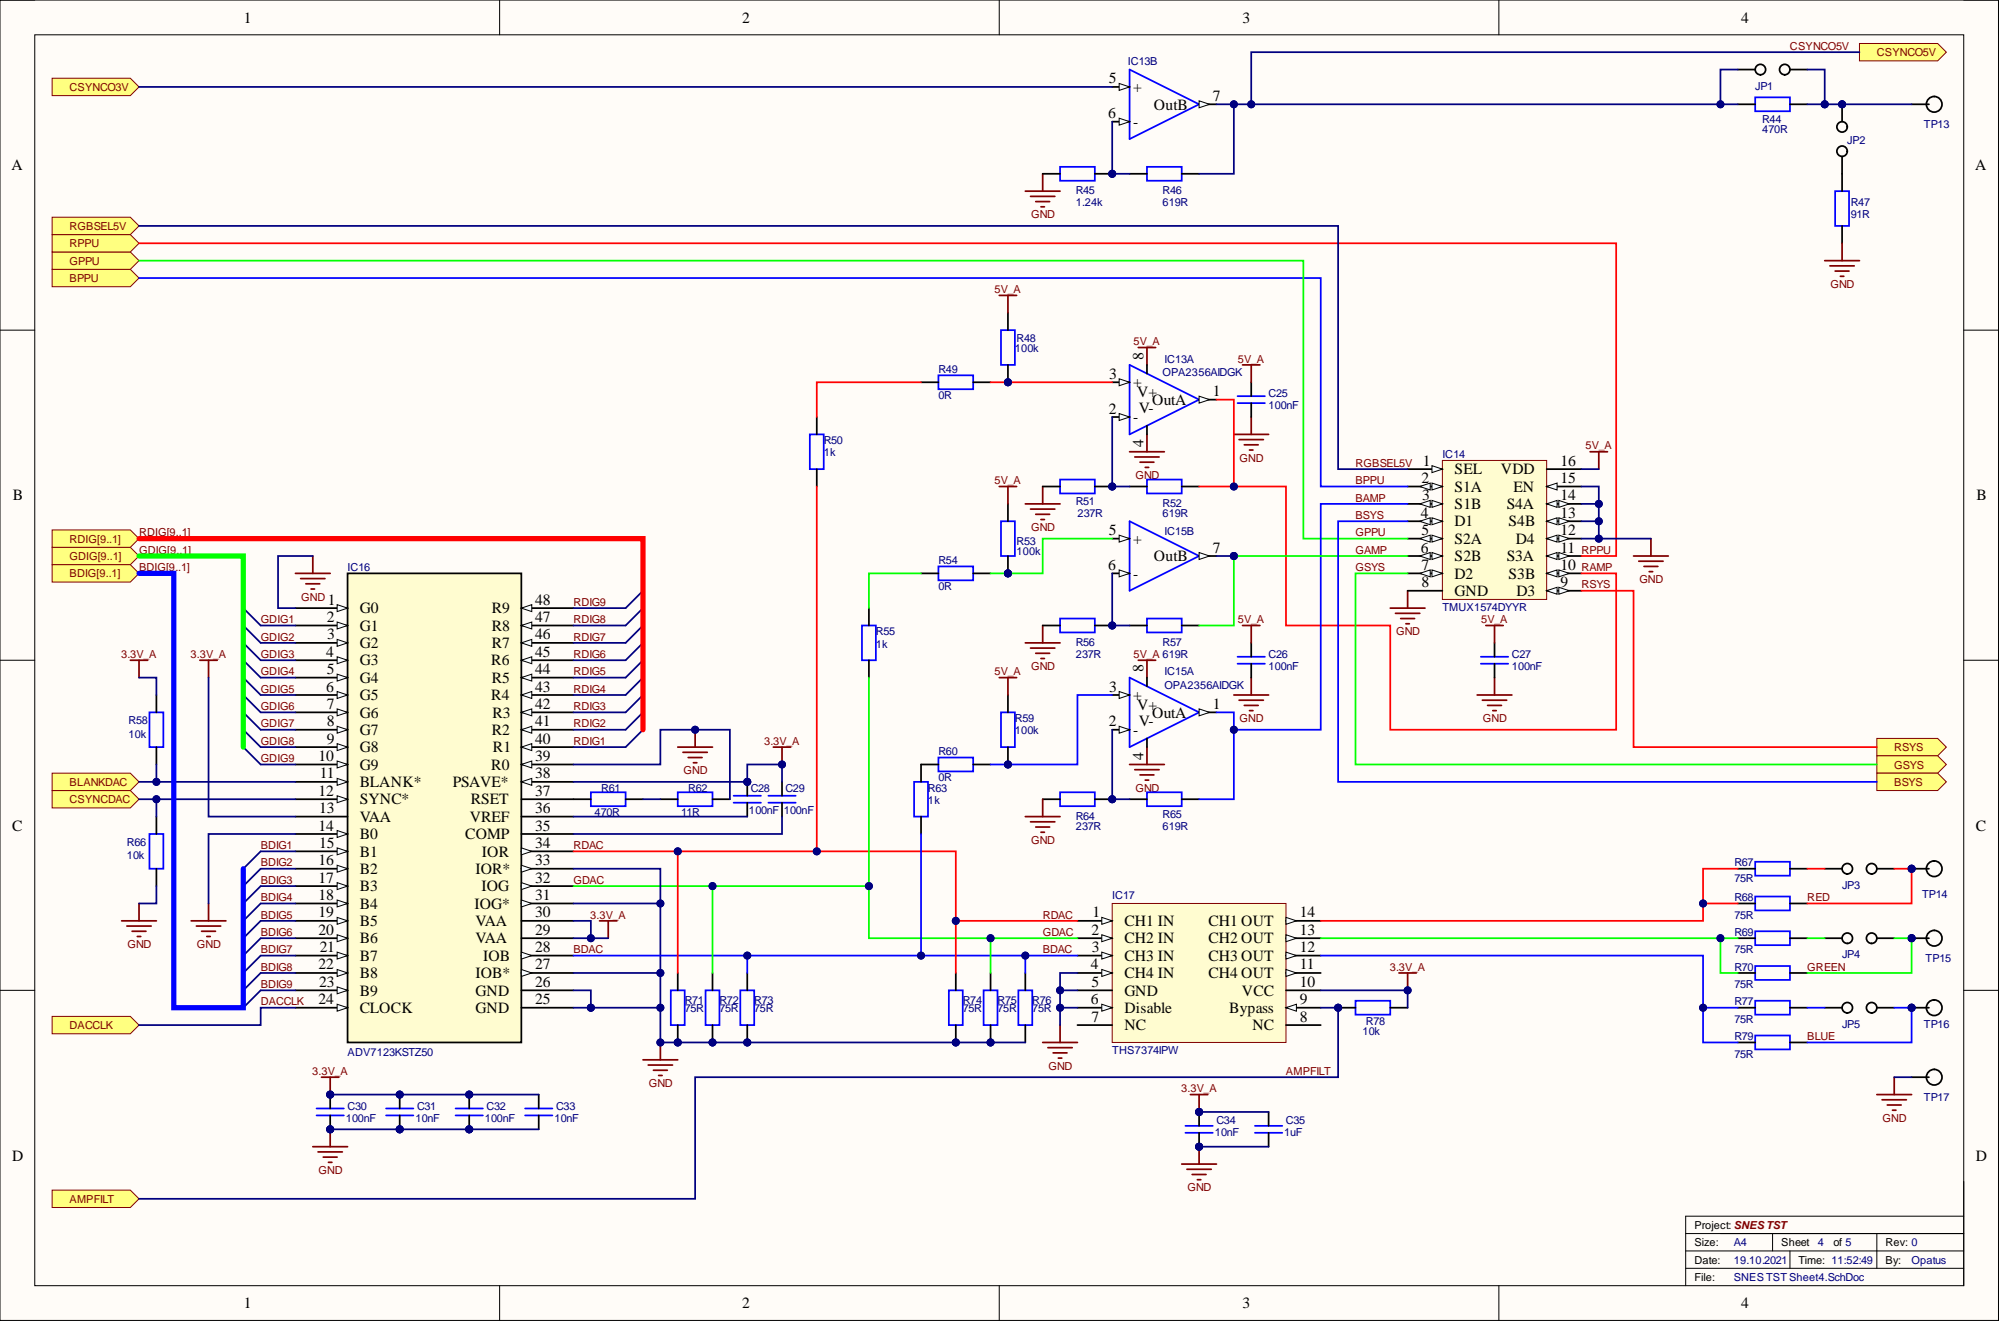
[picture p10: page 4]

GPPU | S2A 5

GDIG[9..1] | | | GAMP | S2B 6 | RPPU
BDIG[9..1] | | IC16 | | | | GSYS | D2 7 | RAMP

GND

SYNC* 12 | R61 R62
VAA 13

BDIG1 BDIG2 BDIG3 BDIG4 | B1 15 B2 16 B3 17 B4 18 | RDAC

Size: A4 | Sheet 4 of 5 | Rev: 0
Date: 19.10.2021 | Time: 11:52:49 | By: Opatus

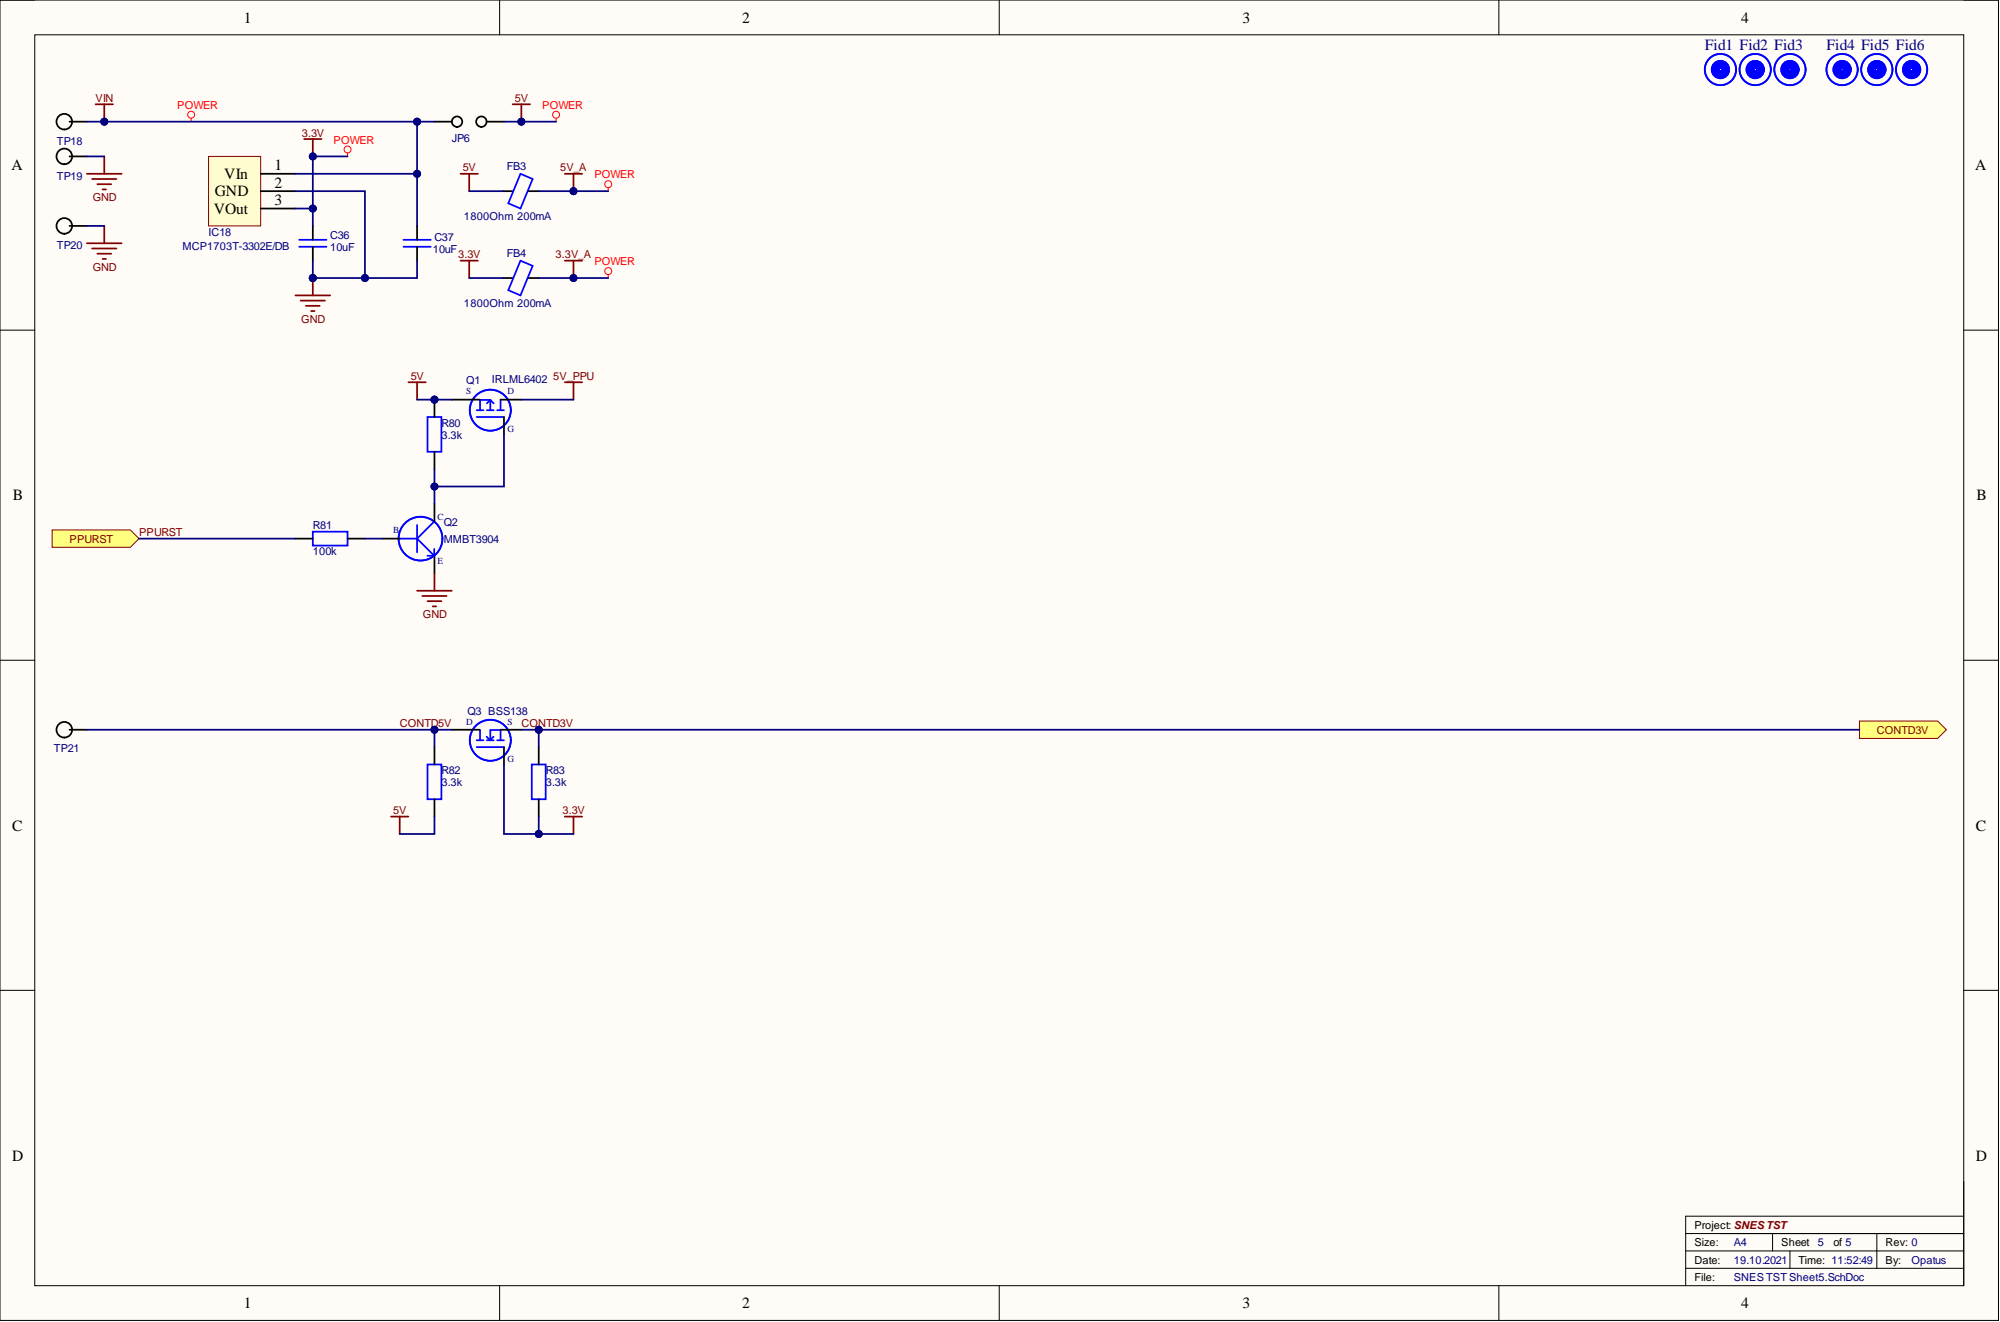
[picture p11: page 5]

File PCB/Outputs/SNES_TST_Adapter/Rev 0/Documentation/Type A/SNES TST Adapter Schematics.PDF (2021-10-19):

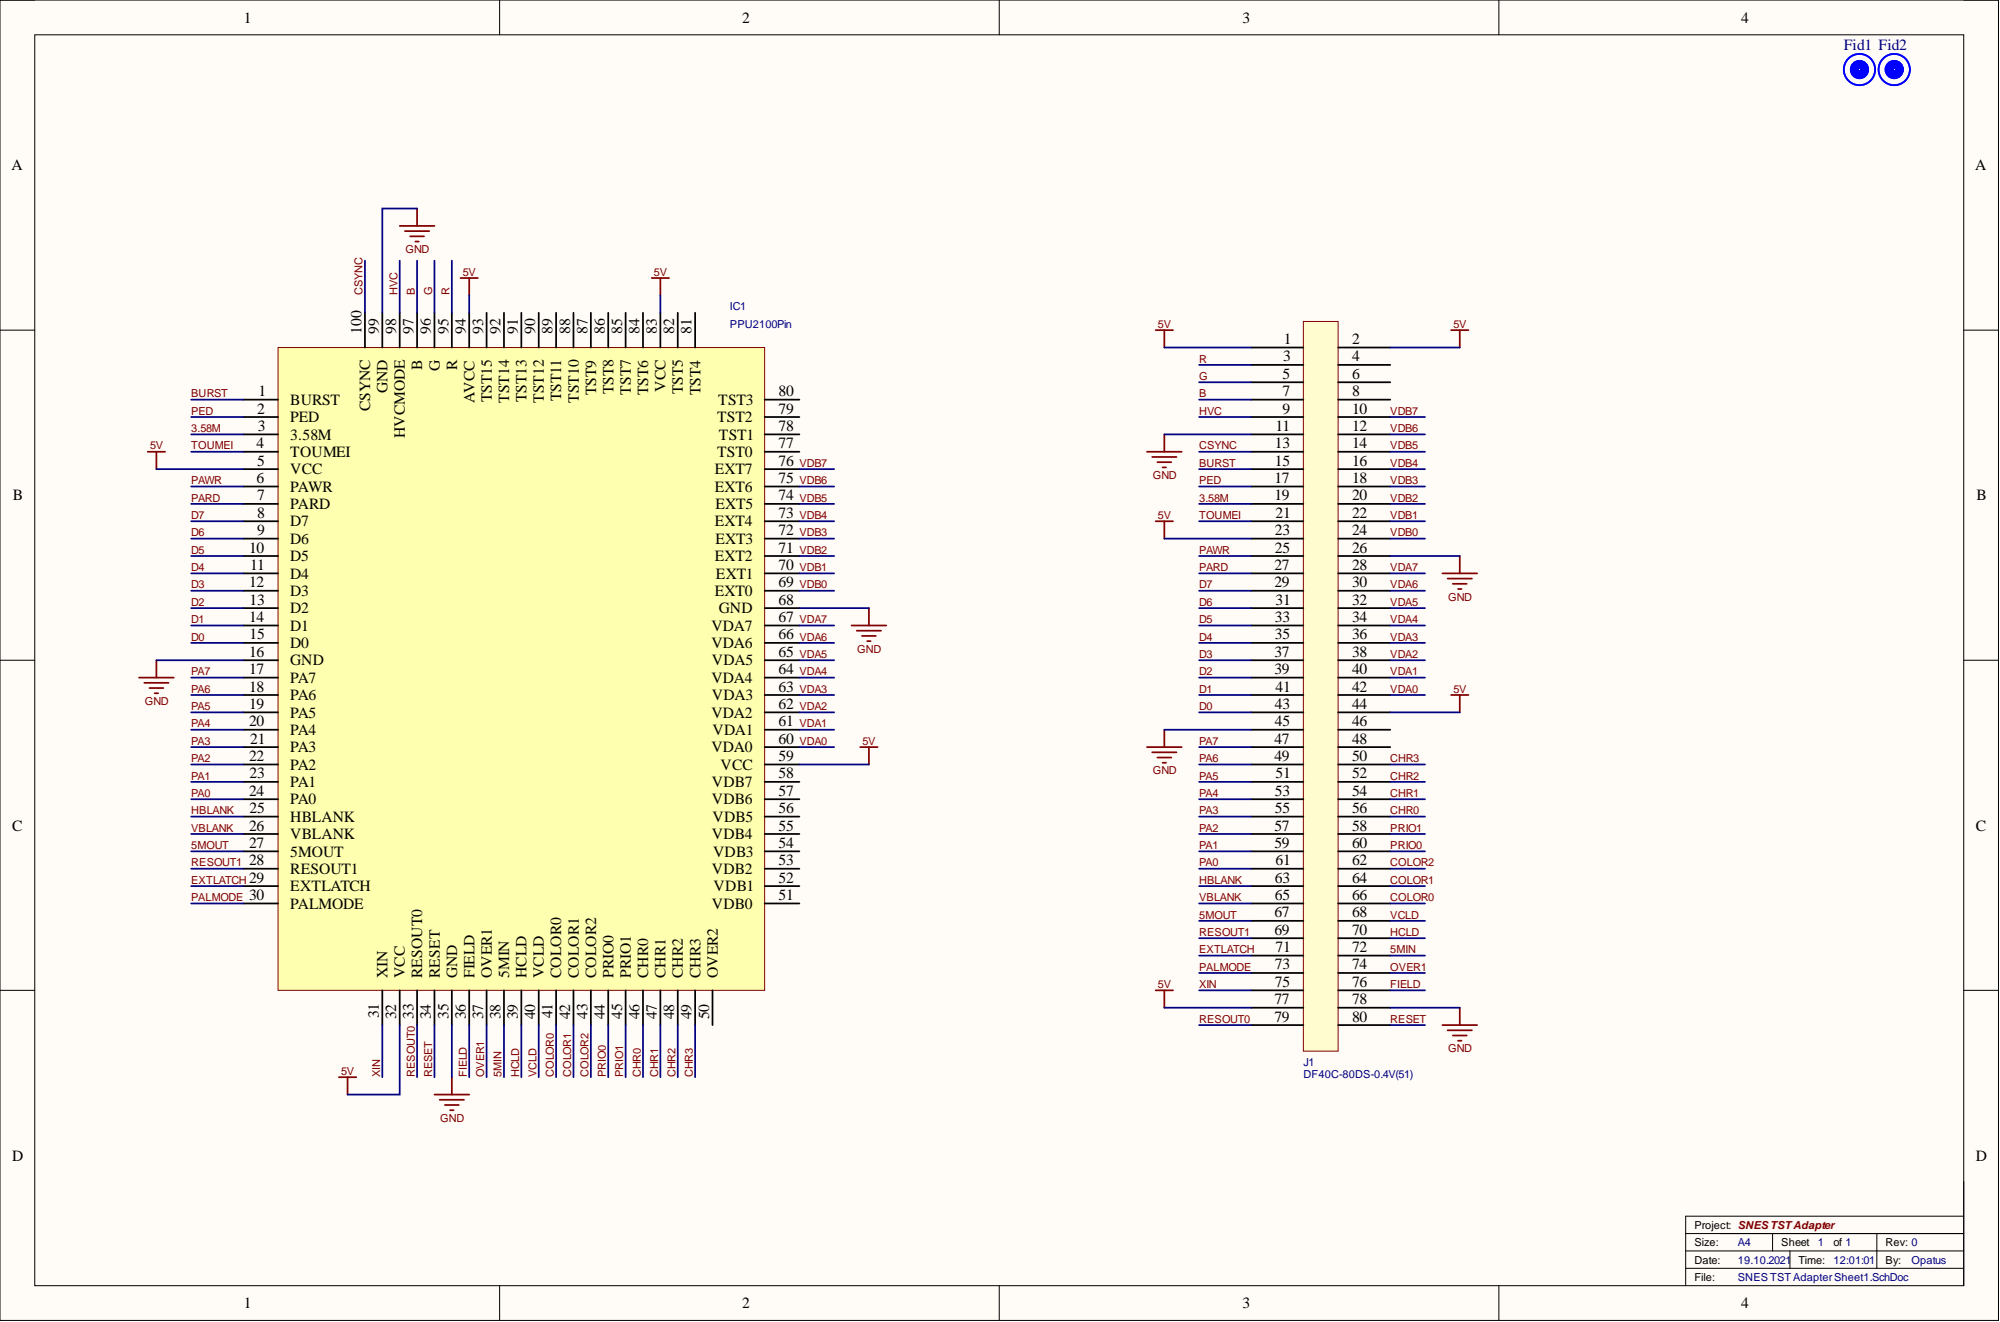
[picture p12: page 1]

5MIN 38 OVER1 37 FIELD 36 GND 35 RESET 34 RESOUT0 33 VCC 32 XIN 31

S i z e : A 4 | S h e e t 1 o f 1 | R e v : 0
D a t e : 1 9 . 1 0 . 2 0 2 | 1 T ime : 1 2 : 0 1 : 0 1 | B y : O p a t u s

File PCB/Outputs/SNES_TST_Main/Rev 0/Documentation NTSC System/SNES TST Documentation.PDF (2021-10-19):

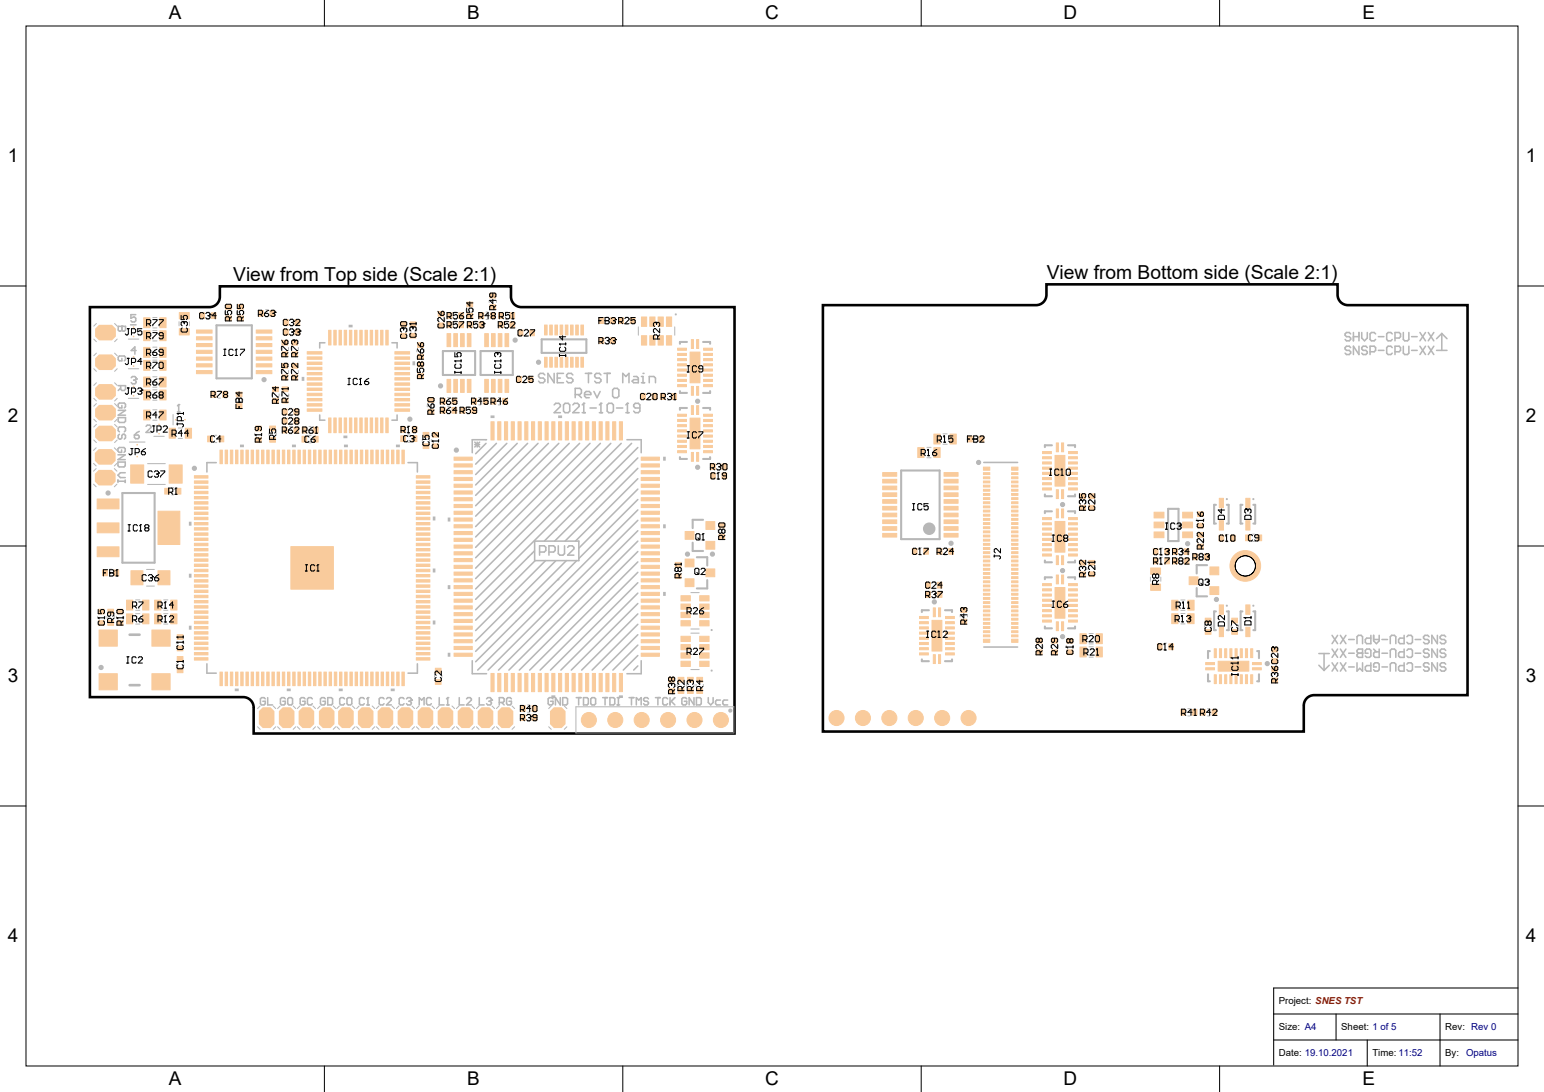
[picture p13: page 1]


View from Front side (Scale 3:2)

View from Back side (Scale 3:2)


View from Front side (Scale 3:2)

View from Back side (Scale 3:2)



Bill Of Materials SNES TST

Pos # | Quantity | Designator | Value | Tolerance | Nominal Voltage | Dielectric | Footprint | Vendor | Part Number
1 | 27 | C1, C2, C3, C4, C5, C6, C11, C12, C13, C14, C15, C16, C17, C18, C19, C20, C21, C22, C23, C24, C25, C26, C27, C28, C29, C30, C32 | 100nF | +-20% | 10V | X7R | Cap_0402_Chip

2 | 4 | C7, C8, C9, C10 | 10pF | +-20% | 10V | X7R | Cap_0402_Chip
3 | 3 | C31, C33, C34 | 10nF | +-20% | 10V | X7R | Cap_0402_Chip
4 | 1 | C35 | 1uF | +-20% | 10V | X7R | Cap_0603_Chip
5 | 1 | C36 | 10uF | +-20% | 10V | X7R | Cap_0805_Chip
6 | 1 | C37 | 10uF | +-20% | 25V | X7R | Cap_1206_Chip
7 | 4 | D1, D2, D3, D4 | Schottky Diode | | | | SOD323 | Diodes | BAT54WS-7-F
8 | 4 | FB1, FB2, FB3, FB4 | 1800Ohm 200mA | | | | Ind_0402_Chip | TDK | MMZ1005S182ET000
9 | 1 | IC1 | 10M04SAE144C8G | | | | EQFP-144_A:1P65_ | Intel | 10M08SAE144C8G
10 | 1 | IC2 | 17.734475 MHz | | | | Quarz 7.5mm | IQD Frequency | LFSPXO020648Bulk
11 | 1 | IC3 | TMUX1219 | | | | SOT23-6 | Texas Instruments | TMUX1219DBVR
12 | 1 | IC5 | SN74HCT541 | | | | TSSOP20 Narrow | Texas Instruments | SN74HCT541PW
13 | 7 | IC6, IC7, IC8, IC9, IC10, IC11, IC12 | LSF0108 | | | | VQFN20 | Texas Instruments | LSF0108RKS
14 | 2 | IC13, IC15 | OPA2356 | | | | MSOP8 | Analog Devices | OPA2356AIDGK
15 | 1 | IC14 | TMUX1574 | | | | SOT-23THIN16 | Texas Instruments | TMUX1574DYYR
16 | 1 | IC16 | ADV7123 | | | | ST_48_ADI | Analog Devices Inc | ADV7123KSTZ50
17 | 1 | IC17 | THS7374 | | | | TSSOP14 | Texas Instruments | THS7374IPW
18 | 1 | IC18 | MCP1703T | | | | SOT223-3 | Microchip | MCP1703T-3302E/DB
19 | 1 | J2 | 80Pole Connector | | | | DF40C-80DP | Hirose Connector | DF40C-80DP-0.4V(51)
20 | 1 | Q1 | IRLML6402 | | | | SOT23_FET | Diodes | IRLML6402
21 | 1 | Q2 | MMBT3904 | | | | SOT23_Transistor | Diodes | MMBT3904
22 | 1 | Q3 | BSS138 | | | | SOT23_FET | Infenion | BSS138
23 | 6 | R1, R4, R28, R50, R55, R63 | 1k | +-1% | | | Res_0402_Chip
24 | 12 | R2, R3, R5, R17, R18, R19, R41, R42, R43, R58, R66, R78 | 10k | +-1% | | | Res_0402_Chip

25 | 5 | R6, R7, R12, R14, R44 | 470R | +-1% | | | Res_0603_Chip
26 | 4 | R8, R11, R13, R21 | 300R | +-1% | | | Res_0603_Chip
27 | 4 | R9, R49, R54, R60 | 0R | | | | Res_0402_Chip
28 | 2 | R15, R20 | 33R | +-1% | | | Res_0603_Chip
29 | 1 | R16 | 100R | +-1% | | | Res_0603_Chip
30 | 8 | R22, R24, R25, R33, R34, R38, R39, R40 | 1.8k | +-1% | | | Res_0402_Chip

31 | 3 | R23, R26, R27 | 10k | +-1% | | | 1206_Array_Chip
32 | 7 | R29, R30, R31, R32, R35, R36, R37 | 200k | +-1% | | | Res_0402_Chip
33 | 1 | R45 | 1.24k | +-1% | | | Res_0402_Chip
34 | 4 | R46, R52, R57, R65 | 619R | +-1% | | | Res_0402_Chip
35 | 1 | R47 | 91R | +-1% | | | Res_0603_Chip
36 | 4 | R48, R53, R59, R81 | 100k | +-1% | | | Res_0402_Chip
37 | 3 | R51, R56, R64 | 237R | +-1% | | | Res_0402_Chip
38 | 1 | R61 | 470R | +-1% | | | Res_0402_Chip
39 | 1 | R62 | 11R | +-1% | | | Res_0402_Chip
40 | 6 | R67, R68, R69, R70, R77, R79 | 75R | +-1% | | | Res_0603_Chip
41 | 6 | R71, R72, R73, R74, R75, R76 | 75R | +-1% | | | Res_0402_Chip
42 | 3 | R80, R82, R83 | 3.3k | +-1% | | | Res_0402_Chip

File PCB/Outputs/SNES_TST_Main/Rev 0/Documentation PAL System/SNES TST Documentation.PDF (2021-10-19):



View from Front side (Scale 3:2)

View from Back side (Scale 3:2)


View from Front side (Scale 3:2)

View from Back side (Scale 3:2)



Bill Of Materials SNES TST

Pos # | Quantity | Designator | Value | Tolerance | Nominal Voltage | Dielectric | Footprint | Vendor | Part Number
1 | 27 | C1, C2, C3, C4, C5, C6, C11, C12, C13, C14, C15, C16, C17, C18, C19, C20, C21, C22, C23, C24, C25, C26, C27, C28, C29, C30, C32 | 100nF | +-20% | 10V | X7R | Cap_0402_Chip

2 | 4 | C7, C8, C9, C10 | 10pF | +-20% | 10V | X7R | Cap_0402_Chip
3 | 3 | C31, C33, C34 | 10nF | +-20% | 10V | X7R | Cap_0402_Chip
4 | 1 | C35 | 1uF | +-20% | 10V | X7R | Cap_0603_Chip
5 | 1 | C36 | 10uF | +-20% | 10V | X7R | Cap_0805_Chip
6 | 1 | C37 | 10uF | +-20% | 25V | X7R | Cap_1206_Chip
7 | 4 | D1, D2, D3, D4 | Schottky Diode | | | | SOD323 | Diodes | BAT54WS-7-F
8 | 4 | FB1, FB2, FB3, FB4 | 1800Ohm 200mA | | | | Ind_0402_Chip | TDK | MMZ1005S182ET000
9 | 1 | IC1 | 10M04SAE144C8G | | | | EQFP-144_A:1P65_ | Intel | 10M08SAE144C8G
10 | 1 | IC2 | 14.318180 MHz | | | | Quarz 7.5mm | IQD Frequency | LFSPXO018538Reel
11 | 1 | IC3 | TMUX1219 | | | | SOT23-6 | Texas Instruments | TMUX1219DBVR
12 | 1 | IC5 | SN74HCT541 | | | | TSSOP20 Narrow | Texas Instruments | SN74HCT541PW
13 | 7 | IC6, IC7, IC8, IC9, IC10, IC11, IC12 | LSF0108 | | | | VQFN20 | Texas Instruments | LSF0108RKS
14 | 2 | IC13, IC15 | OPA2356 | | | | MSOP8 | Analog Devices | OPA2356AIDGK
15 | 1 | IC14 | TMUX1574 | | | | SOT-23THIN16 | Texas Instruments | TMUX1574DYYR
16 | 1 | IC16 | ADV7123 | | | | ST_48_ADI | Analog Devices Inc | ADV7123KSTZ50
17 | 1 | IC17 | THS7374 | | | | TSSOP14 | Texas Instruments | THS7374IPW
18 | 1 | IC18 | MCP1703T | | | | SOT223-3 | Microchip | MCP1703T-3302E/DB
19 | 1 | J2 | 80Pole Connector | | | | DF40C-80DP | Hirose Connector | DF40C-80DP-0.4V(51)
20 | 1 | Q1 | IRLML6402 | | | | SOT23_FET | Diodes | IRLML6402
21 | 1 | Q2 | MMBT3904 | | | | SOT23_Transistor | Diodes | MMBT3904
22 | 1 | Q3 | BSS138 | | | | SOT23_FET | Infenion | BSS138
23 | 6 | R1, R4, R28, R50, R55, R63 | 1k | +-1% | | | Res_0402_Chip
24 | 12 | R2, R3, R5, R17, R18, R19, R41, R42, R43, R58, R66, R78 | 10k | +-1% | | | Res_0402_Chip

25 | 5 | R6, R7, R12, R14, R44 | 470R | +-1% | | | Res_0603_Chip
26 | 4 | R8, R11, R13, R21 | 300R | +-1% | | | Res_0603_Chip
27 | 4 | R10, R49, R54, R60 | 0R | | | | Res_0402_Chip
28 | 2 | R15, R20 | 33R | +-1% | | | Res_0603_Chip
29 | 1 | R16 | 100R | +-1% | | | Res_0603_Chip
30 | 8 | R22, R24, R25, R33, R34, R38, R39, R40 | 1.8k | +-1% | | | Res_0402_Chip

31 | 3 | R23, R26, R27 | 10k | +-1% | | | 1206_Array_Chip
32 | 7 | R29, R30, R31, R32, R35, R36, R37 | 200k | +-1% | | | Res_0402_Chip
33 | 1 | R45 | 1.24k | +-1% | | | Res_0402_Chip
34 | 4 | R46, R52, R57, R65 | 619R | +-1% | | | Res_0402_Chip
35 | 1 | R47 | 91R | +-1% | | | Res_0603_Chip
36 | 4 | R48, R53, R59, R81 | 100k | +-1% | | | Res_0402_Chip
37 | 3 | R51, R56, R64 | 237R | +-1% | | | Res_0402_Chip
38 | 1 | R61 | 470R | +-1% | | | Res_0402_Chip
39 | 1 | R62 | 11R | +-1% | | | Res_0402_Chip
40 | 6 | R67, R68, R69, R70, R77, R79 | 75R | +-1% | | | Res_0603_Chip
41 | 6 | R71, R72, R73, R74, R75, R76 | 75R | +-1% | | | Res_0402_Chip
42 | 3 | R80, R82, R83 | 3.3k | +-1% | | | Res_0402_Chip

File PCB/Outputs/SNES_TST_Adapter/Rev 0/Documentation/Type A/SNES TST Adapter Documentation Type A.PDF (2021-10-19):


View from Top side (Scale 4:1)

View from Bottom side (Scale 4:1)

SNES TST Adapter Type A


View from Front side (Scale 3:1)

View from Left side (Scale 3:1)

View from Right side (Scale 3:1)

View from Top side (Scale 3:1)

View from Bottom side (Scale 3:1)

View from Back side (Scale 3:1)


View from Front side (Scale 3:1)

View from Back side (Scale 3:1)



Bill Of Materials SNES TST Adapter Type A

Line # | Quantity | Designator | Comment | Tolerance | Nominal Voltage | Dielectric | Footprint | Vendor | Manufacturer_Part_Number
1 | 1 | J1 | 80Pole Connector | | | | DF40C-80DS | Hirose Connector | DF40C-80DS-0.4V(51)

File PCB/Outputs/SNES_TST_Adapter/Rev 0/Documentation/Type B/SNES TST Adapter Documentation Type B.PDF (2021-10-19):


View from Top side (Scale 4:1)

View from Bottom side (Scale 4:1)

SNES TST Adapter Type B


View from Front side (Scale 3:1)

View from Left side (Scale 3:1)

View from Right side (Scale 3:1)

View from Top side (Scale 3:1)

View from Bottom side (Scale 3:1)

View from Back side (Scale 3:1)


View from Front side (Scale 3:1)

View from Back side (Scale 3:1)



Bill Of Materials SNES TST Adapter Type B

Line # | Quantity | Designator | Comment | Tolerance | Nominal Voltage | Dielectric | Footprint | Vendor | Manufacturer_Part_Number
1 | 1 | J1 | 80Pole Connector | | | | DF40C-80DS | Hirose Connector | DF40C-80DS-0.4V(51)







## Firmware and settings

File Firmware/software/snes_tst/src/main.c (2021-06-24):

/*********************************************************************************
 *
 * This file is part of the SNES TST project.
 *
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
 *
 * main.c
 *
 *  Created on: 12 May 2021
 *      Author: Opatus
 */

#include "config.h"
#include "system.h"
#include "alt_types.h"
#include "osd.h"

int main() {
	alt_u32 controller;
	/*
	alt_u32 testRGBOut;
	alt_u16 testDataR,testDataG, testDataB;
	alt_u8 testSync = 4, syncFlag = 0;
	initializeConfig ();

	testDataR = 116;
	testDataG = 116;
	testDataB = 232;
	*/
	/* Event loop never exits. */
	while (1){


		controller = IORD_ALTERA_AVALON_PIO_DATA(CONTROLLER_DATA_BASE);
		IOWR_ALTERA_AVALON_PIO_DATA(CONFIG_OUTPUT_BASE, controller);

/*		if(syncFlag){
			testDataR = 116;
			//if(testDataG < 465) testDataG++;
			//else testDataG = 116;
		}
		else{
			//testDataG = 116;
			if(testDataR < 465) testDataR++;
			else testDataR = 116;
			//testDataR = 300;
		}
		testRGBOut = testDataR + (testDataG << 9) + (testDataB << 18);

		//testDataR = testSync * 90;
		IOWR_ALTERA_AVALON_PIO_DATA(CONFIG_OUTPUT_BASE, testRGBOut);

		testSync = IORD_ALTERA_AVALON_PIO_DATA(SYNC_BASE);
		syncFlag = (testSync & 0b001) ? 1 : 0;
	*/
	}

	return 0;
}

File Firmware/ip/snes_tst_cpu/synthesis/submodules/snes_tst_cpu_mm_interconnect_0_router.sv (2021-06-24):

// (C) 2001-2020 Intel Corporation. All rights reserved.
// Your use of Intel Corporation's design tools, logic functions and other 
// software and tools, and its AMPP partner logic functions, and any output 
// files from any of the foregoing (including device programming or simulation 
// files), and any associated documentation or information are expressly subject 
// to the terms and conditions of the Intel Program License Subscription 
// Agreement, Intel FPGA IP License Agreement, or other applicable 
// license agreement, including, without limitation, that your use is for the 
// sole purpose of programming logic devices manufactured by Intel and sold by 
// Intel or its authorized distributors.  Please refer to the applicable 
// agreement for further details.



// Your use of Altera Corporation's design tools, logic functions and other 
// software and tools, and its AMPP partner logic functions, and any output 
// files any of the foregoing (including device programming or simulation 
// files), and any associated documentation or information are expressly subject 
// to the terms and conditions of the Altera Program License Subscription 
// Agreement, Altera MegaCore Function License Agreement, or other applicable 
// license agreement, including, without limitation, that your use is for the 
// sole purpose of programming logic devices manufactured by Altera and sold by 
// Altera or its authorized distributors.  Please refer to the applicable 
// agreement for further details.


// $Id: //acds/rel/20.1std/ip/merlin/altera_merlin_router/altera_merlin_router.sv.terp#1 $
// $Revision: #1 $
// $Date: 2019/10/06 $
// $Author: psgswbuild $

// -------------------------------------------------------
// Merlin Router
//
// Asserts the appropriate one-hot encoded channel based on 
// either (a) the address or (b) the dest id. The DECODER_TYPE
// parameter controls this behaviour. 0 means address decoder,
// 1 means dest id decoder.
//
// In the case of (a), it also sets the destination id.
// -------------------------------------------------------

`timescale 1 ns / 1 ns

module snes_tst_cpu_mm_interconnect_0_router_default_decode
  #(
     parameter DEFAULT_CHANNEL = 2,
               DEFAULT_WR_CHANNEL = -1,
               DEFAULT_RD_CHANNEL = -1,
               DEFAULT_DESTID = 6 
   )
  (output [87 - 84 : 0] default_destination_id,
   output [9-1 : 0] default_wr_channel,
   output [9-1 : 0] default_rd_channel,
   output [9-1 : 0] default_src_channel
  );

  assign default_destination_id = 
    DEFAULT_DESTID[87 - 84 : 0];

  generate
    if (DEFAULT_CHANNEL == -1) begin : no_default_channel_assignment
      assign default_src_channel = '0;
    end
    else begin : default_channel_assignment
      assign default_src_channel = 9'b1 << DEFAULT_CHANNEL;
    end
  endgenerate

  generate
    if (DEFAULT_RD_CHANNEL == -1) begin : no_default_rw_channel_assignment
      assign default_wr_channel = '0;
      assign default_rd_channel = '0;
    end
    else begin : default_rw_channel_assignment
      assign default_wr_channel = 9'b1 << DEFAULT_WR_CHANNEL;
      assign default_rd_channel = 9'b1 << DEFAULT_RD_CHANNEL;
    end
  endgenerate

endmodule


module snes_tst_cpu_mm_interconnect_0_router
(
    // -------------------
    // Clock & Reset
    // -------------------
    input clk,
    input reset,

    // -------------------
    // Command Sink (Input)
    // -------------------
    input                       sink_valid,
    input  [101-1 : 0]    sink_data,
    input                       sink_startofpacket,
    input                       sink_endofpacket,
    output                      sink_ready,

    // -------------------
    // Command Source (Output)
    // -------------------
    output                          src_valid,
    output reg [101-1    : 0] src_data,
    output reg [9-1 : 0] src_channel,
    output                          src_startofpacket,
    output                          src_endofpacket,
    input                           src_ready
);

    // -------------------------------------------------------
    // Local parameters and variables
    // -------------------------------------------------------
    localparam PKT_ADDR_H = 55;
    localparam PKT_ADDR_L = 36;
    localparam PKT_DEST_ID_H = 87;
    localparam PKT_DEST_ID_L = 84;
    localparam PKT_PROTECTION_H = 91;
    localparam PKT_PROTECTION_L = 89;
    localparam ST_DATA_W = 101;
    localparam ST_CHANNEL_W = 9;
    localparam DECODER_TYPE = 0;

    localparam PKT_TRANS_WRITE = 58;
    localparam PKT_TRANS_READ  = 59;

    localparam PKT_ADDR_W = PKT_ADDR_H-PKT_ADDR_L + 1;
    localparam PKT_DEST_ID_W = PKT_DEST_ID_H-PKT_DEST_ID_L + 1;



    // -------------------------------------------------------
    // Figure out the number of bits to mask off for each slave span
    // during address decoding
    // -------------------------------------------------------
    localparam PAD0 = log2ceil(64'h2000 - 64'h0); 
    localparam PAD1 = log2ceil(64'h20008 - 64'h20000); 
    localparam PAD2 = log2ceil(64'h21800 - 64'h21000); 
    localparam PAD3 = log2ceil(64'h21808 - 64'h21800); 
    localparam PAD4 = log2ceil(64'h21830 - 64'h21820); 
    localparam PAD5 = log2ceil(64'h21860 - 64'h21840); 
    localparam PAD6 = log2ceil(64'h21880 - 64'h21860); 
    localparam PAD7 = log2ceil(64'h21890 - 64'h21880); 
    localparam PAD8 = log2ceil(64'h100000 - 64'h80000); 
    // -------------------------------------------------------
    // Work out which address bits are significant based on the
    // address range of the slaves. If the required width is too
    // large or too small, we use the address field width instead.
    // -------------------------------------------------------
    localparam ADDR_RANGE = 64'h100000;
    localparam RANGE_ADDR_WIDTH = log2ceil(ADDR_RANGE);
    localparam OPTIMIZED_ADDR_H = (RANGE_ADDR_WIDTH > PKT_ADDR_W) ||
                                  (RANGE_ADDR_WIDTH == 0) ?
                                        PKT_ADDR_H :
                                        PKT_ADDR_L + RANGE_ADDR_WIDTH - 1;

    localparam RG = RANGE_ADDR_WIDTH-1;
    localparam REAL_ADDRESS_RANGE = OPTIMIZED_ADDR_H - PKT_ADDR_L;

      reg [PKT_ADDR_W-1 : 0] address;
      always @* begin
        address = {PKT_ADDR_W{1'b0}};
        address [REAL_ADDRESS_RANGE:0] = sink_data[OPTIMIZED_ADDR_H : PKT_ADDR_L];
      end   

    // -------------------------------------------------------
    // Pass almost everything through, untouched
    // -------------------------------------------------------
    assign sink_ready        = src_ready;
    assign src_valid         = sink_valid;
    assign src_startofpacket = sink_startofpacket;
    assign src_endofpacket   = sink_endofpacket;
    wire [PKT_DEST_ID_W-1:0] default_destid;
    wire [9-1 : 0] default_src_channel;
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

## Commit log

2021-05-27 RGB routing
    Changed the RGB routing
    [SNES TST Sheet2.SchDoc]
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2021-06-16 v_count was completely useless
    v_count was connected to VBLANK for some reason, hopefully it is corrected.
    [SNES_TST.v]
2021-10-06 PCB Update
    added TOUMEI, FIELD to FPGA
    removed BURST, PED from FPGA
    PPU2 resettable
    pull-up resistors for outgoing 5V signals
    pull-down resistors for CIC0, CIC1, RESETIN
    the controller can be turned off
    added Fiducials
    [SNES TST Sheet1.SchDoc, SNES TST Sheet2.SchDoc, SNES TST Sheet3.SchDoc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]
2021-10-06 Silkscreen update
    Minor silkscreen update
    [SNES TST Adapter GPM RGB APU.PcbDoc, SNES TST Adapter.PcbDoc, SNES TST Adapter.PrjPcb]
2021-10-07 Documentation update
    updated Draftsman
    updated BOM
    added 3.3V option for oscillator
    [SNES TST Sheet1.SchDoc, SNES TST Sheet2.SchDoc, SNES TST Sheet3.SchDoc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]
2021-10-08 Schematics
    added 5th schematics page
    [SNES TST Sheet1.SchDoc, SNES TST Sheet2.SchDoc, SNES TST Sheet3.SchDoc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]
2021-10-14 Small changes in PCB
    Slight routing changes
    Modified Draftsman document
    [SNES TST Adapter.PrjPcb]
2021-10-14 Documentation update
    Added Draftsman to the adapter
    [SNES TST Adapter GPM RGB APU.PcbDoc, SNES TST Adapter.PcbDoc, SNES TST Adapter.PrjPcb]
2021-10-15 Altium Release Test
    Added OutJob files
    Added Integrated Libraries
    [SNES TST Adapter GPM RGB APU.PcbDoc, SNES TST Adapter Sheet1.SchDoc, SNES TST Adapter Type A.PcbDoc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]
2021-10-15 Update SNES TST Adapter.PrjPcb
    [SNES TST Adapter.PrjPcb]
2021-10-15 Board origin was moved to corner
    [SNES TST Adapter Type A.PcbDoc, SNES TST Adapter Type B.PcbDoc]
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2021-10-15 SNES TST Adapter Rev0 Release
    SNES TST Adapter Initial Release
    [Bill of Materials-SNES TST Adapter(SNES TST Adapter).xlsx, SNES TST Adapter Sheet1.SchDoc, SNES TST Adapter Type A(SNES TST Adapter).step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]
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2021-10-15 Prepare for SNES TST Release
    [SNES TST.PrjPcb]
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2021-10-15 Initial Release for SNES TST (Rev 0)
    Note: In the TST SNES Documentation (NTSC System) file the Realistic View of the bottom side is slightly smaller than it should. The PAL System Variant does not have this bug. Altium is being Altium...
    [Bill of Materials-SNES TST(NTSC System).xlsx, Bill of Materials-SNES TST(PAL System).xlsx, SNES TST Sheet1.SchDoc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]
2021-10-19 Removed paste from PPU2
    [SNES TST Adapter Type A.PcbDoc, SNES TST Adapter Type B.PcbDoc, SNES TST Adapter.PrjPcb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]
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2021-10-19 Updated Rev0 PCB Release
    PPU2 paste removed
    Pin connector paste removed
    Altium Releaser still does not work properly
    [Bill of Materials-SNES TST Adapter(SNES TST Adapter).xlsx, Bill of Materials-SNES TST(NTSC System).xlsx, Bill of Materials-SNES TST(PAL System).xlsx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]
2021-10-22 Removed THS7374 for NTSC
    Expermintal removal of the THS7374 Amp by the NTSC variant
    Removed paste for jumpers
    [SNES TST Sheet2.SchDoc, SNES TST Sheet3.SchDoc, SNES TST Sheet4.SchDoc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]
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2021-10-24 Added Pull-down to Ampfilt
    Added Pull-down to Ampfilt to identify if the THS7374 mounted is or not.
    Changed feedback resistor value for the op amps.
    [SNES TST Sheet1.SchDoc, SNES TST Sheet2.SchDoc, SNES TST Sheet3.SchDoc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]
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2021-10-26 Added Solutions to BOM
    [SNES TST Sheet1.SchDoc, SNES TST Sheet2.SchDoc, SNES TST Sheet3.SchDoc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]
2021-10-27 BOM update
    Also the off-grid diodes in the schematics have been changed
    [SNES TST Sheet1.SchDoc, SNES TST Sheet2.SchDoc, SNES TST Sheet3.SchDoc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]
2021-10-28 Remade some components
    Due to a bug some step files have gone missing after opening the PCB file.
    [SNES TST Adapter Sheet1.SchDoc, SNES TST Adapter Type A.PcbDoc, SNES TST Adapter Type B.PcbDoc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]
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2021-10-29 Changed the amplifier divider for NTSC
    [SNES TST Sheet1.SchDoc, SNES TST Sheet2.SchDoc, SNES TST Sheet4.SchDoc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]
2021-11-02 Added Bypass Cap for PPU_AVCC; Changed schematics readibility
    [PPU2 And Connector.SchDoc, Power And Voltage Shifters.SchDoc, RGB Video Output.SchDoc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]
2021-11-02 added comments for FPGA signals
    [PPU2 And Connector.SchDoc, Power And Voltage Shifters.SchDoc, RGB Video Output.SchDoc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]
2021-11-03 Reorganized folder structure
    Renamed SNES TST to SNES TST MAIN
    [BOM Modified.xlsx, Bill of Materials-SNES TST Adapter(SNES TST Adapter).xlsx, Bill of Materials-SNES TST(NTSC System).xlsx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]
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2021-11-03 Cleanup 3.3V_A layout to not include the digital ADV7123 signals
    Increased Revision to Rev 1
    [PPU2 And Connector.SchDoc, Power And Voltage Shifters.SchDoc, RGB Video Output.SchDoc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]
2021-11-04 LSF0108 changed to TXB0108 due to FPGA input leakage concerns
    Most likely was not an issue
    [Power And Voltage Shifters.SchDoc, SNES TST Main.PrjPcb]
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2021-11-07 Finished rerouting due to the part changes
    [PPU2 And Connector.SchDoc, Power And Voltage Shifters.SchDoc, RGB Video Output.SchDoc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]
2021-11-08 Removed errors from schematics validation
    [PPU2 And Connector.SchDoc, Power And Voltage Shifters.SchDoc, RGB Video Output.SchDoc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]
2021-11-11 Updated PAL video output impedance
    [Power And Voltage Shifters.SchDoc, SNES TST Main.PrjPcb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]
2021-11-14 Corrected the D4 patch connection
    [PPU2 And Connector.SchDoc]
2021-11-18 Changing LDO to SMPS and LDO for efficiency
    [PPU2 And Connector.SchDoc, Power And Voltage Shifters.SchDoc, Power.SchDoc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]
2021-11-19 Finished the DC-DC converter layout
    [PPU2 And Connector.SchDoc, Power.SchDoc, RGB Video Output.SchDoc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]
2021-11-22 Removed pad overhang from adapter boards
    [Power.SchDoc, SNES TST Adapter Sheet1.SchDoc, SNES TST Adapter Type A.PcbDoc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]
2021-11-23 Changed a few TST input pins, AMPFILT and DACCLK on the FPGA
    [PPU2 And Connector.SchDoc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]
2021-11-24 Changing voltage shifters WIP
    [PPU2 And Connector.SchDoc, RGB Video Output.SchDoc, SNES TST Main.PrjPcb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]
2021-11-25 Continuing the voltage shifter modifications
    [PPU2 And Connector.SchDoc, Voltage Shifters.SchDoc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]
2021-11-25 Finished voltage shifter update
    [PPU2 And Connector.SchDoc, Power.SchDoc, RGB Video Output.SchDoc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]
2021-11-26 Added bypass caps to voltage shifters
    [Power.SchDoc, Voltage Shifters.SchDoc]
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2021-11-30 Added a Top page to schematics
    [PPU2 And Connector.SchDoc, Power.SchDoc, RGB Video Output.SchDoc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]
2021-12-01 Changed the project hierarchy
    [BOM Modified.xlsx, Connectors.SchDoc, PPU2 And Connector.SchDoc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]
2021-12-01 Added pullup res to PPRESET
    Also added pullup/pulldown to CSYNCO3V, for configuration
    [Connectors.SchDoc, PPU2.SchDoc, Power.SchDoc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]
2021-12-02 Slight analog video change
    [RGB Video Output.SchDoc]
2021-12-02 slight changes
    BOMDoc and draftsman update
    [SNES TST Adapter Sheet1.SchDoc, SNES TST Adapter.PrjPcb, SNES TST Main.PrjPcb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]
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2021-12-05 Small corrections
    [Power.SchDoc, Voltage Shifters.SchDoc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]
2021-12-06 Removed the subcarrier parts from the PAL Variant
    [SNES TST Main.PrjPcb]
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2021-12-08 Updated the FPGA pin assignment for the new pinout
    [Power.SchDoc]
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

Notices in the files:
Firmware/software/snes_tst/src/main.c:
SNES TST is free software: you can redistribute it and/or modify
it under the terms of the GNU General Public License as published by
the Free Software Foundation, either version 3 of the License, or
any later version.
